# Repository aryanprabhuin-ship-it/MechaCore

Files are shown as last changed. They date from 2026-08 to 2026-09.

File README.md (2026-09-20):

# MechaCore

MechaCore is my custom 60% (61 key) wired mechanical keyboard, its built around a **Raspberry Pi Pico 2** and a completely hand routed 2 layer PCB.

so basicaly i wanted to make a keyboard where i didnt just download somebody elses pcb and put switches in it.. i wanted to actualy understand the matrix, diodes, stabilizers, routing, plate tolerances and how the pcb fits inside a real printable case. i designed the layout, schematic, pcb and the full case from scratch using kicad + fusion 360 and ngl the case part took way more trys then i expected lol

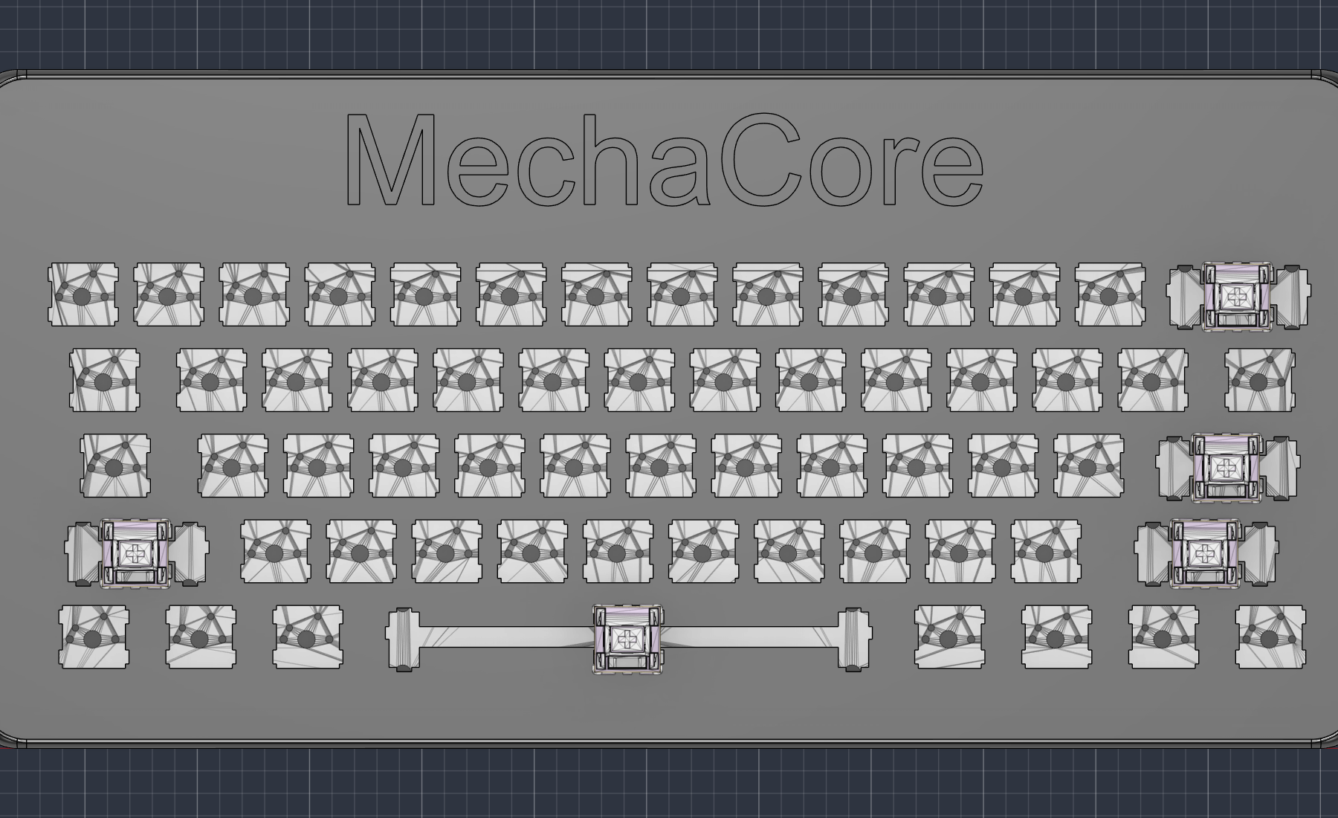
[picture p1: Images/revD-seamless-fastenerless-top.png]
MechaCore Rev D fastenerless enclosure


## why i made this

i use a keyboard for school, coding and pretty much everything, but most custom boards i liked was either super expensive or still used a ready made pcb. making MechaCore was kinda my excuse to learn the full hardware pipeline instead of only assembling parts

main goals i set for myself :

- design a proper **60% ANSI PCB** in kicad with 61 switches
- wire the full matrix directly to a Raspberry Pi Pico 2
- hand route every row, column and diode connection on a real 2 layer board
- support screw-in stabilizers for backspace, enter, both shifts and the 6.25u spacebar
- make a rounded 3d printable bottom case + switch plate in fusion 360
- keep the files actualy manufacturable, not just make a nice looking render
- learn the full pipeline : keyboard layout -> schematic -> pcb -> 3d export -> case -> production files

the routing was easily the most painful bit because the board has 61 switches and basically no room for lazy paths 😭 after alot of moving tracks between front/back copper the pcb reached **0 unconnected items**, which felt kinda unreal after staring at ratsnest lines for so long

## project status

this repo has the full hardware design, cad, manufacturing exports and the Pico 2 firmware. the PCB and case geometry is done, the matrix pinout is locked and the firmware is ready to copy straight onto the controller. the current enclosure is **Rev D**, a two-piece fastenerless design with no screw heads or locator tips visible from the top

whats included :

- kicad project, schematic and fully routed pcb
- full 3d cad (`.f3d`, `.step` and printable `.stl` files)
- current Rev D fused bottom case and blind-snap switch plate exports
- retained Rev B and Rev C CAD archives for design-history / rollback
- production files (bom, positions, designators, ipc netlist and gerber zip)
- 60% ANSI keyboard layout json
- schematic and individual fabrication layer PDFs
- complete Pico 2 firmware with the matching CircuitPython UF2

current hardware summary :

| | |
|---|---|
| Layout | 60% ANSI, 61 keys |
| Controller | Raspberry Pi Pico 2 |
| Connectivity | wired USB through the Pico |
| Matrix | 14 columns x 5 rows, directly connected to the Pico |
| Diodes | 61x Slkor 1N4148W switching diodes, one per key (SOD-123, COL2ROW) |
| Stabilizers | Durock Clear screw-in V2 (6.25u space + 2u / 2.25u / 2.75u) |
| Switches | Akko V3 Penguin Pro |
| Keycaps | Plum Blossom cherry profile shine-through PBT |
| Case | 2 printed parts: fused bottom shell + blind-snap switch plate, no loose case hardware |
| PCB | 2 layer FR4, 300mm x 135.8mm, 1.6mm, green soldermask |
| Firmware | dependency free CircuitPython 10.2.1 USB HID firmware, 2 layers |

the dark rounded case and the big **MechaCore** name on the plate is what kinda gave the whole board its look. the pink plum blossom keycaps should contrast with it nicely, atleast thats the plan once it becomes a real physical board

## images

### current Rev D enclosure

the final top surface is continuous. all six screw stacks from the earlier revisions were removed and both kinematic locator receivers were made blind, so there are no fastener heads or locator dots visible around the key field

Rev D clean top with no visible fasteners

the bottom case still uses six reinforced mounting stations, dual load-spreader spines and the round/expansion datum system. the screw sockets are now undercut receivers for the fused plate collets

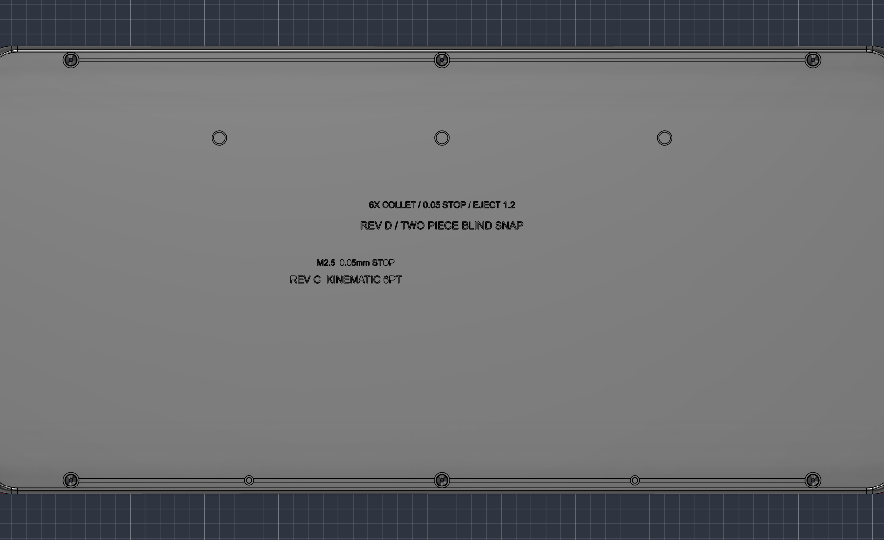
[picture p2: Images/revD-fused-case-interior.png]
Rev D fused bottom-case interior


each plate lock has a split 3.6mm shaft, stepped insertion pilot and 4.3mm retention bead. the relief direction alternates around the plate to reduce sensitivity to print-axis anisotropy

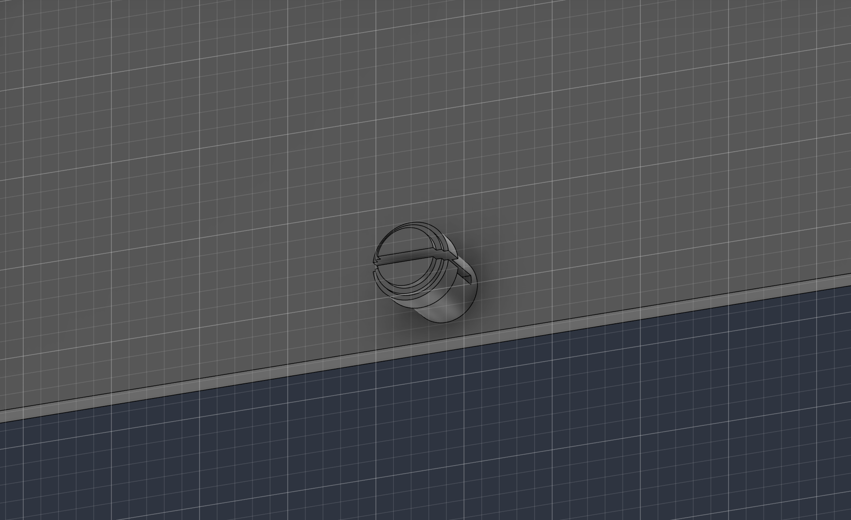
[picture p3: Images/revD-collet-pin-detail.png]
Rev D fused snap-collet detail


the four hollow-cup feet, three PCB deflection catches and six underside ejector ports are fused into the two main printed bodies instead of being separate hardware

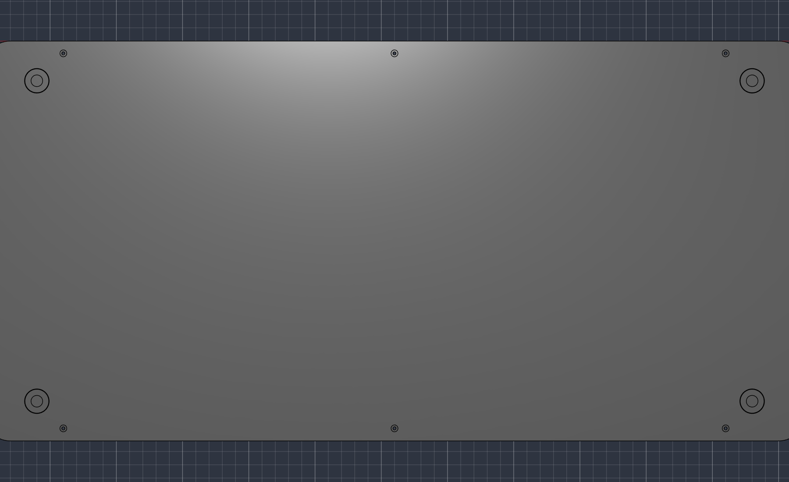
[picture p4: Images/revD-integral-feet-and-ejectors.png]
Rev D integral feet and ejector ports


### PCB and electronics

the complete 14x5 matrix, all 61 switches, 61 diodes, stabilizer symbols and Pico connections are kept in the same KiCad project

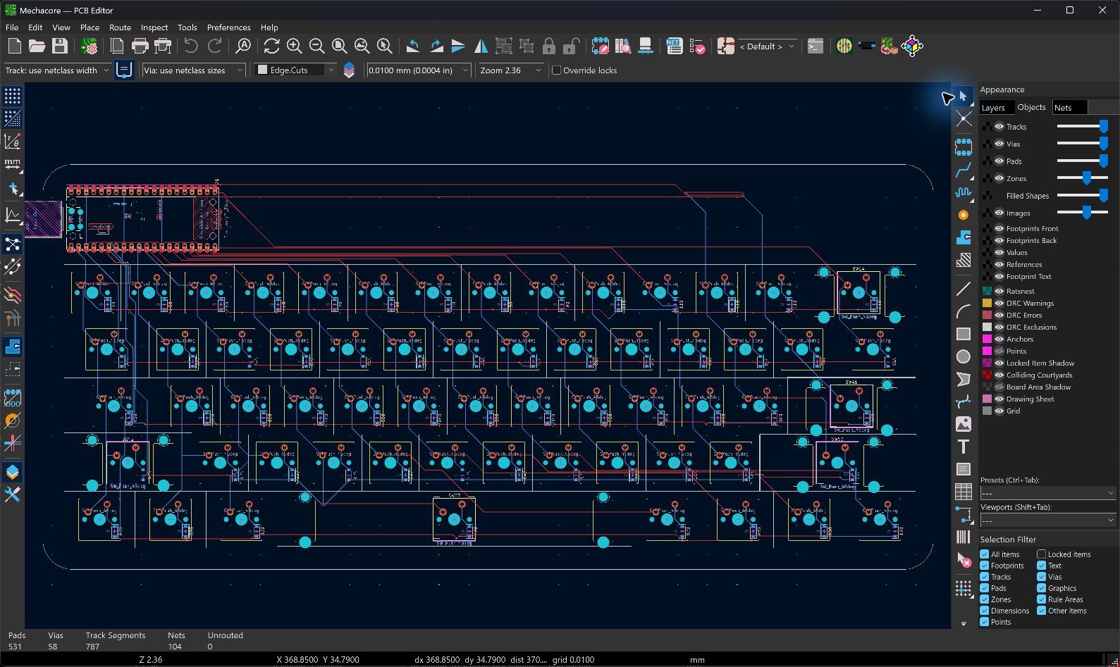
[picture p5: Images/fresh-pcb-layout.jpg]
MechaCore PCB routing in KiCad

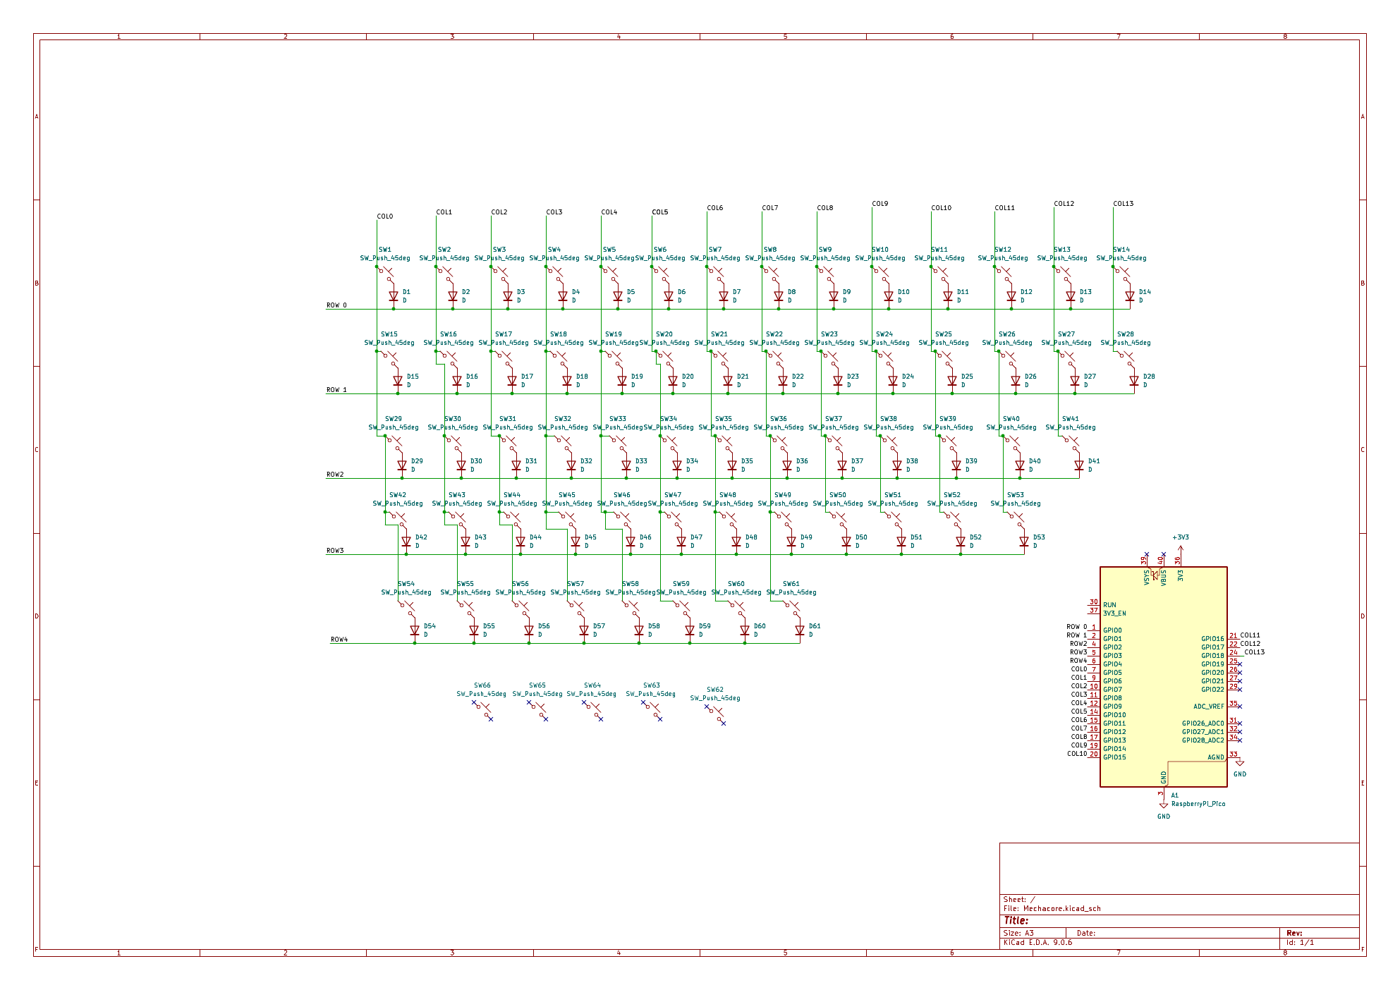
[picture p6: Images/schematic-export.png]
MechaCore schematic

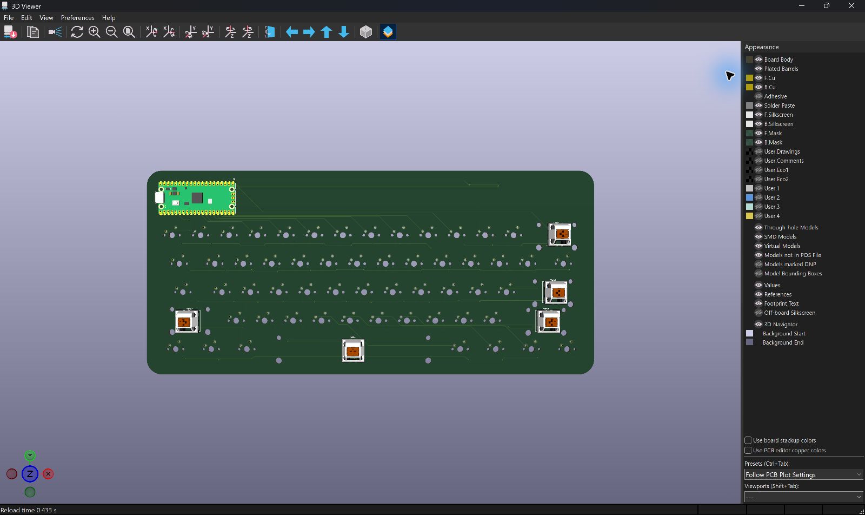
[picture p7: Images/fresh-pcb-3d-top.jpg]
PCB top view in KiCad 3D Viewer

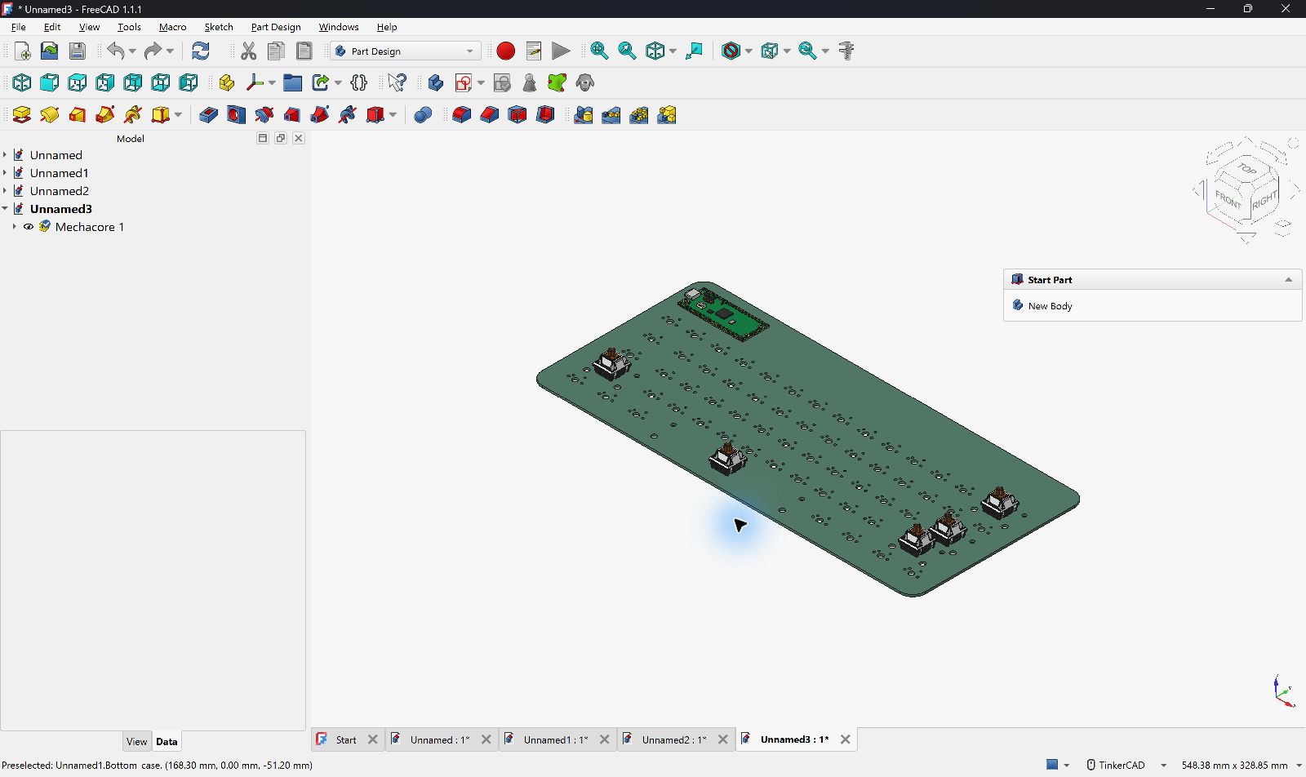
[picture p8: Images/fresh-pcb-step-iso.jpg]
Exported PCB STEP checked in CAD


### earlier enclosure development

these views show the original shell/plate work and are kept as design-history references. the Rev D files below are the current manufacturing set

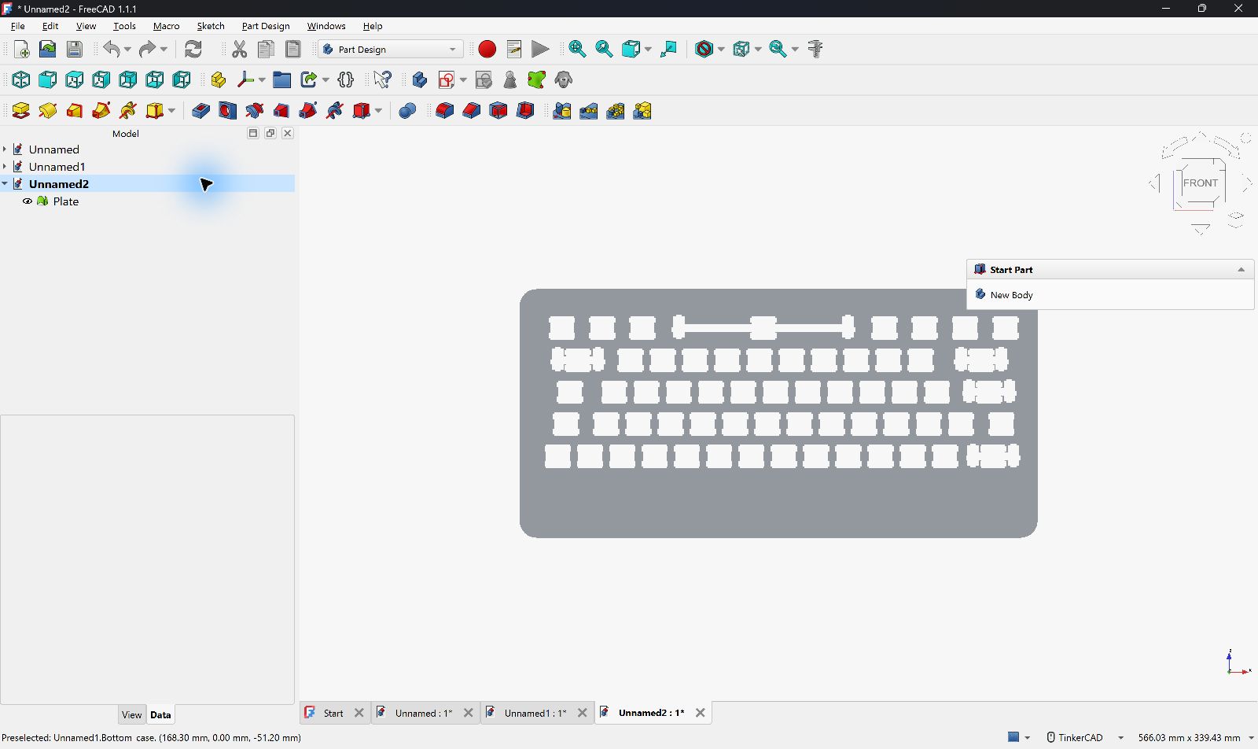
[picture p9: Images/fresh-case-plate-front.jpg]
Original switch and stabilizer plate cutouts

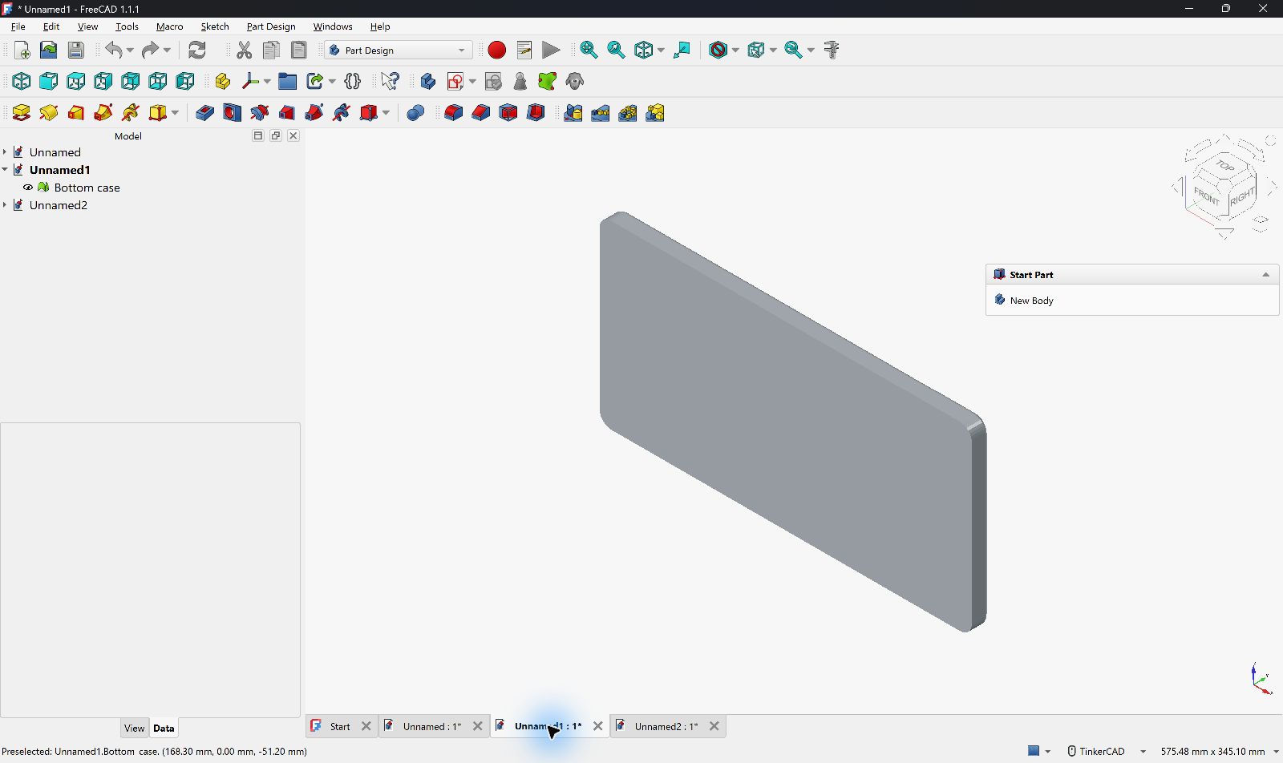
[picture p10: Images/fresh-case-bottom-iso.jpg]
Original bottom case shell


## repository structure

```text
MechaCore/
├── 3D/
│   ├── Case/                 Fusion archives, STEP assemblies and case/plate STLs
│   └── PCB/                  PCB reference model exported as STEP and STL
├── BOM Pics/                 supplier/cart screenshots used during BOM research
├── firmware/                 CircuitPython firmware, boot setup and Pico 2 UF2
├── Images/                   README-ready project, PCB and CAD images
├── layout/                   60% ANSI keyboard-layout JSON
├── PCB/                      KiCad project, schematic, routed PCB and backups
├── PDFs/                     schematic plus individual fabrication-layer PDFs
├── production/               Gerbers, BOM, positions, designators and IPC netlist
├── Working screen shot/      working CAD captures, including Rev B, C and D views
├── bom.csv                   build-cost and purchase-planning BOM
└── README.md
```

`Images/` contains the curated screenshots used by this README. `Working screen shot/` keeps the corresponding working captures so the documentation images can be replaced or compared without opening Fusion or KiCad.

## repo file checklist

important current files in this repo :

- `PCB/Mechacore.kicad_pro`
- `PCB/Mechacore.kicad_sch`
- `PCB/Mechacore.kicad_pcb`
- `3D/Case/Mechacore-overengineered-revD.f3d`  (editable current enclosure)
- `3D/Case/Mechacore-overengineered-revD.step`  (current neutral CAD assembly)
- `3D/Case/Plate-blind-snap-revD.stl`  (print-ready plate with fused collets)
- `3D/Case/Bottom-case-fused-revD.stl`  (print-ready fused case)
- `3D/PCB/Mechacore.step`
- `3D/PCB/Mechacore.stl`
- `layout/keyboard-layout.json`
- `production/bom.csv`
- `production/positions.csv`
- `production/designators.csv`
- `production/netlist.ipc`
- `production/Mechacore.zip`  (gerbers)
- `bom.csv`  (build cost / purchase list)
- `PDFs/Mechacore.pdf`  (schematic print)
- `firmware/code.py`  (MechaCore key scanner + keymap)
- `firmware/boot.py`  (USB name + HID setup)
- `firmware/adafruit-circuitpython-raspberry_pi_pico2-en_US-10.2.1.uf2`

## cad

designed in **Fusion 360**. the current editable enclosure is `3D/Case/Mechacore-overengineered-revD.f3d`, with a STEP assembly beside it and separate production STLs for the case and plate

Rev D is intentionally overengineered while keeping the physical part count low. the Fusion timeline contains **289 items and 52 parameters**, but the finished enclosure is exactly **two printable solids** with no component/hardware occurrences:

- six fused, split snap collets on the plate underside
- six matching undercut sockets inside the reinforced case bosses
- 0.10mm radial retention interference and 0.05mm controlled seating travel
- alternating collet-split directions for print-anisotropy compensation
- round + expansion kinematic locators hidden below a 0.6mm plate roof
- six 1.2mm underside ejector ports for non-destructive service removal
- fused hollow-cup feet and fused PCB anti-sag catches
- existing wall gussets and dual load-spreader spines retained for the clamp/load path

to assemble it, align the blind locator pair and press evenly above the six edge stations until the retention beads seat in their undercut cavities. for removal, release the stations progressively through the underside ejector ports instead of bending one side of the plate

older CAD is intentionally kept in the same folder:

| Revision | Purpose |
|---|---|
| Original / unsuffixed | initial shell and plate baseline |
| Rev B | first proper six-point M2.5 screw mounting system |
| Rev C | screws, inserts, isolation washers, compression stops, feet and PCB supports |
| **Rev D** | current two-piece blind-snap design with fused service features |

the exact pcb was also exported as both STEP and STL in `3D/PCB/`. i used that model inside the case design instead of guessing the board outline, especially for the rounded corners, Pico usb opening, solder clearance and stabilizer holes

## firmware

firmware is finaly in the repo under `firmware/`. its a small dependency free CircuitPython setup written just for MechaCore, so theres no KMK folder, package install or placeholder pin list to fix later. the GPIO map was copied directly from the finished kicad PCB and the bundled UF2 is the official stable [CircuitPython Pico 2 build](https://circuitpython.org/board/raspberry_pi_pico2/)

| | |
|---|---|
| Runtime | CircuitPython 10.2.1 for Raspberry Pi Pico 2 |
| Rows | GP0, GP1, GP2, GP3, GP4 |
| Columns | GP5 through GP18 |
| Matrix | 5 rows x 14 columns, 61 populated positions |
| Diodes | column anode to row cathode (`columns_to_anodes=True`) |
| Debounce | 3 stable scans at 2ms, around 6ms total |
| USB | standard keyboard + consumer control HID |
| Rollover | 6 normal keys plus all modifiers |

the base layer follows the actual keycap layout :

```text
`     1   2   3   4   5   6   7   8   9   0   -   =   Backspace
Tab   Q   W   E   R   T   Y   U   I   O   P   [   ]   \
Caps  A   S   D   F   G   H   J   K   L   ;   '       Enter
Shift Z   X   C   V   B   N   M   ,   .   /           Shift
Ctrl  Win Alt             Space             Alt Win Menu/Fn Ctrl
```

the Menu key still works like a normal Menu key when tapped. hold it for 180ms or press it together with another key and it becomes Fn

- `Fn + backtick` = Escape
- `Fn + 1` through `Fn + =` = F1 through F12
- `Fn + Backspace` = Delete
- `Fn + U / I / O / P` = Home / Up / End / Page Up
- `Fn + J / K / L / ;` = Left / Down / Right / Page Down
- `Fn + Q / W / E` = Previous track / Play-Pause / Next track
- `Fn + M`, `Fn + ,`, `Fn + .`, `Fn + /` = Mute / Volume Down / Volume Up / Play-Pause

### flashing it

1. hold the BOOTSEL button on the Pico 2 while plugging the keyboard into usb
2. open the new `RP2350` drive and copy `firmware/adafruit-circuitpython-raspberry_pi_pico2-en_US-10.2.1.uf2` onto it
3. after it restarts as `CIRCUITPY`, copy `firmware/boot.py` and `firmware/code.py` to the root of that drive
4. unplug and reconnect once so the USB setup from `boot.py` loads cleanly

thats it, no pin edits or extra libraries are needed. the keyboard shows up as **MechaCore** and the files stay editable from the `CIRCUITPY` drive if i ever wanna change the layout later

## bom (summary)

full purchase list is in `bom.csv`. these prices are the rough planned cost in indian rupees, nothing was ordered yet

| # | Name | Purpose | Qty | Cost (₹) | Distributor | Link |
|---|---|---|-----|---|---|---|
| 1 | PCB fabrication | 2 layer MechaCore boards | 5 boards | 5288 | Robu | [Buy](https://robu.in/product/online-pcb-manufacturing-service/) |
| 2 | 3D printed case | bottom shell + plate | 1 set | own funded| Hack Club | — |
| 3 | Plum Blossom Cherry Profile Shine-Through PBT Keycap Set | keycaps to actualy type on | 1 set | own funded | Curiosity Caps | [Buy](https://curiositycaps.in/products/plum-blossom-cherry-profile-shine-through-dye-sublimation-pbt-keycap-set) |
| 4 | Durock Clear Screw-In Stabilizers V2 | keeps the large keys stable | 1 set | 1595 | StacksKB | [Buy](https://stackskb.com/store/durock-clear-screw-in-stabilizers-v2/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) |
| 5 | Akko V3 Penguin Pro Switch (Pack of 45) | mechanical switches + spares | 1 pack | 1,199 | StacksKB | [Buy](https://stackskb.com/store/akko-v3-cream-black-pro-switch-pack-of-45/) |
| 6 | Raspberry Pi Pico 2 | microcontroller / the brains | 1 | 519 | Robu | [Buy](https://robu.in/product/raspberry-pi-pico-2/) |
| 7 | Slkor 1N4148W SOD-123 switching diodes | one diode per switch + some spares | 70 pcs | 100.10 | Robu | [Buy](https://robu.in/product/1n4148w-slkor-75v-1v-4ns-150ma-sod-123-switching-diodes-rohs/) |

**rough total bom cost : ₹8,701.10**

---

thanks for reading,, if you build one or spot something weird feel free to open a issue. this was my first full keyboard pcb + case made from scratch so its deffinately not perfect but i learnt a insane amount making it :)

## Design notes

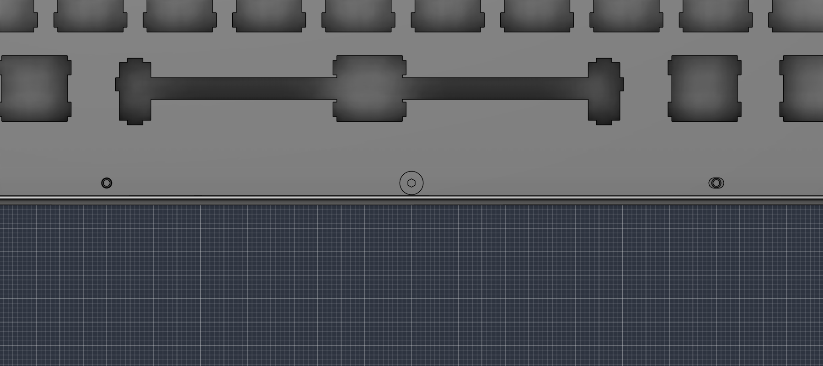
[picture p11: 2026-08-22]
Images/revC-kinematic-locators-detail.png

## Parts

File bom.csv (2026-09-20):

Part | Link | Provider | Price(Rupees)
PCB | https://robu.in/product/online-pcb-manufacturing-service/ | Robu | 5288
3d printing | hackclub | hackclub | own funded
Plum Blossom Cherry | https://curiositycaps.in/products/plum-blossom-cherry-profile-shine-through-dye-sublimation-pbt-keycap-set | Curiosity caps | own funded
Durock Clear Screw-In Stabilizers V2 | https://stackskb.com/store/durock-clear-screw-in-stabilizers-v2/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 | StacksKB | 1595
Akko V3 Penguin Pro Switch (Pack of 45) | https://stackskb.com/store/akko-v3-cream-black-pro-switch-pack-of-45/ | StacksKB | 1,199
Pico 2 | https://robu.in/product/raspberry-pi-pico-2/ | Robu | 519
Slkor 1N4148W SOD-123 switching diodes (70 pcs) | https://robu.in/product/1n4148w-slkor-75v-1v-4ns-150ma-sod-123-switching-diodes-rohs/ | Robu | 100.1
 |  |  | 8701.1

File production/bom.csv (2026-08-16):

Designator | Footprint | Quantity | Value | LCSC Part #
A1 | RaspberryPi_Pico_Common_Unspecified | 1 | RaspberryPi_Pico
D1, D10, D11, D12, D13, D14, D15, D16, D17, D18, D19, D2, D20, D21, D22, D23, D24, D25, D26, D27, D28, D29, D3, D30, D31, D32, D33, D34, D35, D36, D37, D38, D39, D4, D40, D41, D42, D43, D44, D45, D46, D47, D48, D49, D5, D50, D51, D52, D53, D54, D55, D56, D57, D58, D59, D6, D60, D61, D7, D8, D9 | D_SOD-123 | 61 | 1N4148W
SW1, SW10, SW11, SW12, SW13, SW16, SW17, SW18, SW19, SW2, SW20, SW21, SW22, SW23, SW24, SW25, SW26, SW27, SW3, SW30, SW31, SW32, SW33, SW34, SW35, SW36, SW37, SW38, SW39, SW4, SW40, SW43, SW44, SW45, SW46, SW47, SW48, SW49, SW5, SW50, SW51, SW52, SW6, SW7, SW8, SW9 | SW_MX_1u | 46 | SW_Push_45deg
SW14 | SW_Cherry_MX_PCB_2.00u | 1 | SW_Push_45deg
SW15, SW28 | SW_MX_1.5u | 2 | SW_Push_45deg
SW29 | SW_MX_1.75u | 1 | SW_Push_45deg
SW41, SW42 | SW_Cherry_MX_PCB_2.25u | 2 | SW_Push_45deg
SW53 | SW_Cherry_MX_PCB_2.75u | 1 | SW_Push_45deg
SW54, SW55, SW56, SW58, SW59, SW60, SW61 | SW_MX_1.25u | 7 | SW_Push_45deg
SW57 | SW_Cherry_MX_PCB_6.25u | 1 | SW_Push_45deg
SW62 | STAB_MX_2u | 1 | SW_Push_45deg
SW63, SW64 | STAB_MX_2.25u | 2 | SW_Push_45deg
SW65 | STAB_MX_2.75u | 1 | SW_Push_45deg
SW66 | STAB_MX_6.25u | 1 | SW_Push_45deg

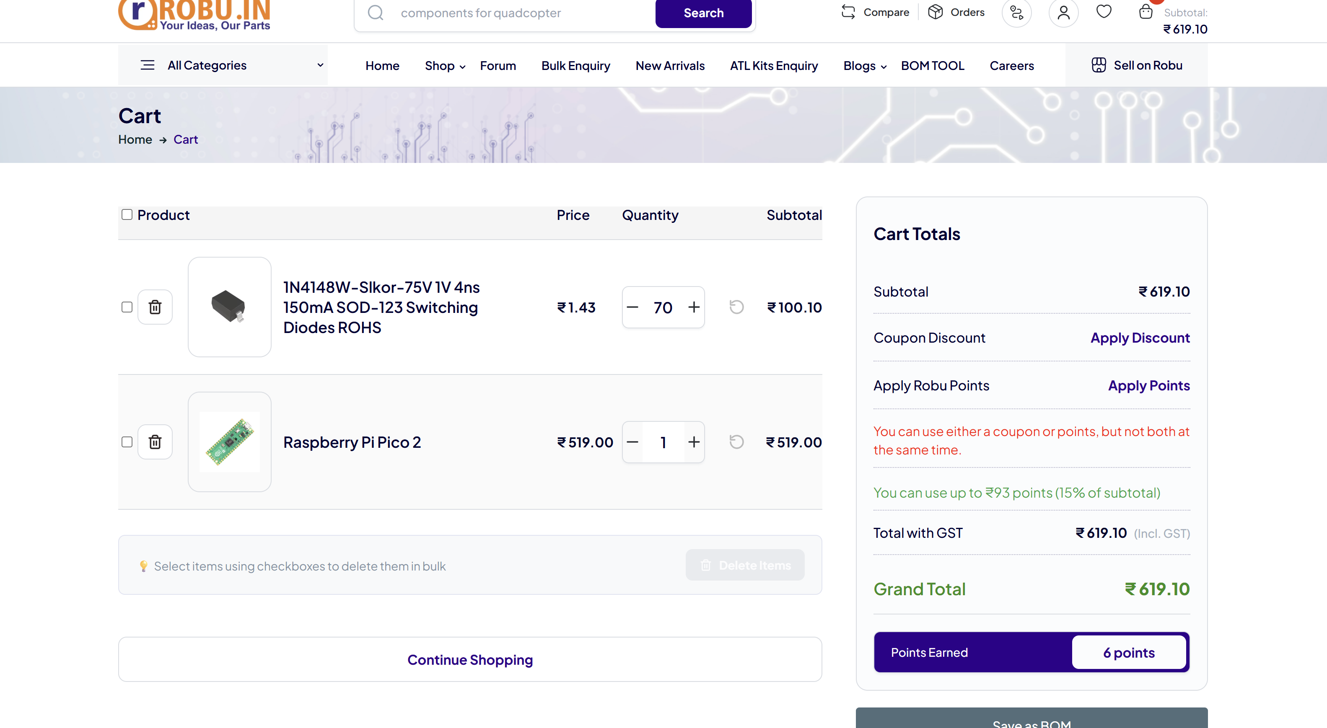
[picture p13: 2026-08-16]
BOM Pics/Screenshot 2026-08-16 123939.png

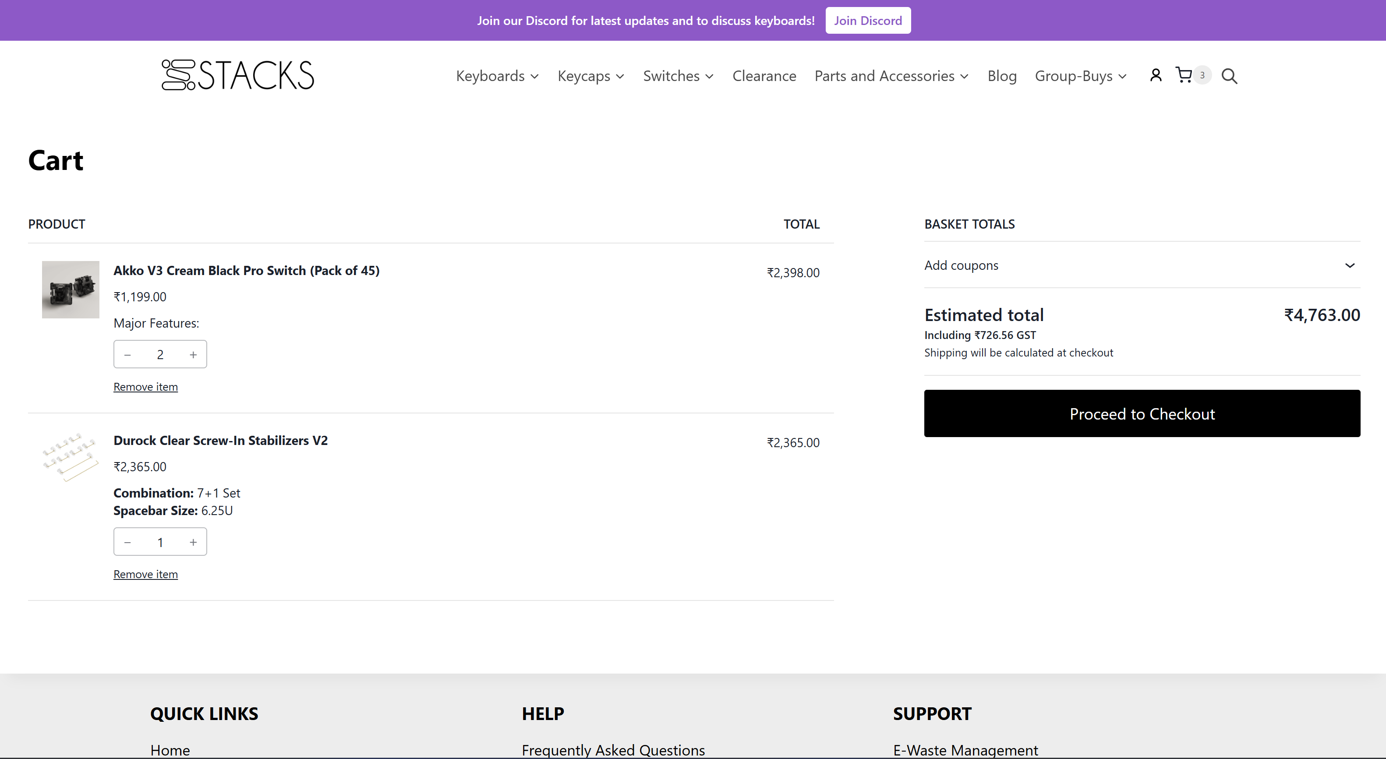
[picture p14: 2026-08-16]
BOM Pics/Screenshot 2026-08-16 123547.png

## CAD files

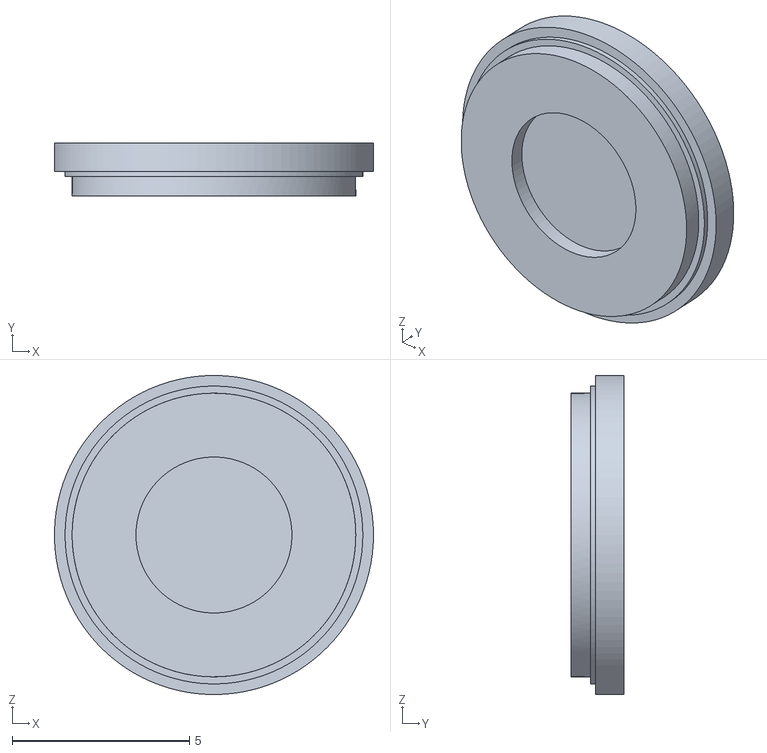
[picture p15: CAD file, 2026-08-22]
3D/Case/TPU-foot-8mm-revC.stl
9.00 x 1.50 x 9.00

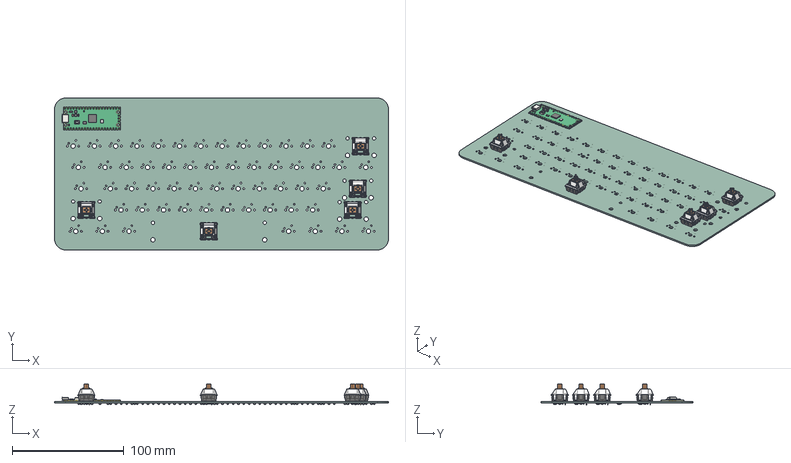
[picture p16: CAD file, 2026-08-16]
3D/PCB/Mechacore.step
298.8 x 136.0 x 18.6 mm
RaspberryPi_Pico_Module_KiCad
SW_Cherry_MX_PCB x 5
D_SOD-123 x 61
Mechacore_PCB

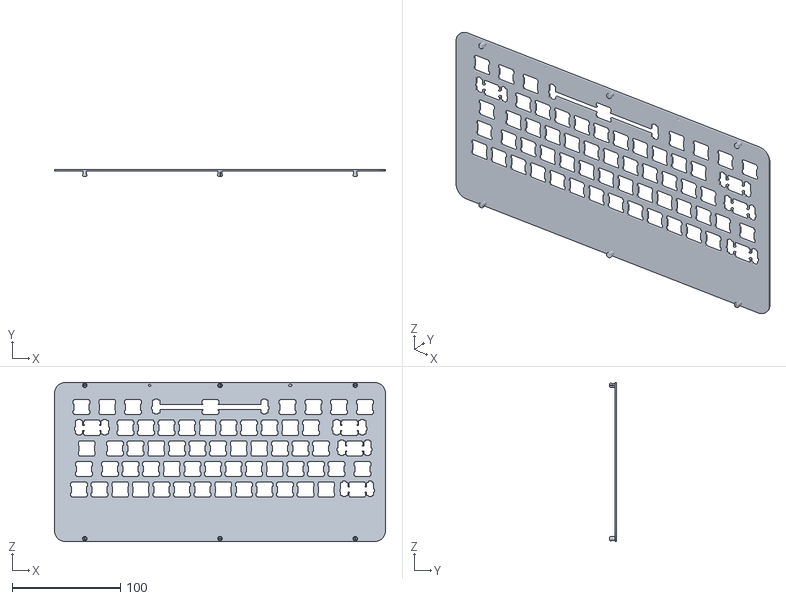
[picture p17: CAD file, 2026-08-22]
3D/Case/Plate-blind-snap-revD.stl
305.9 x 6.80 x 147.0

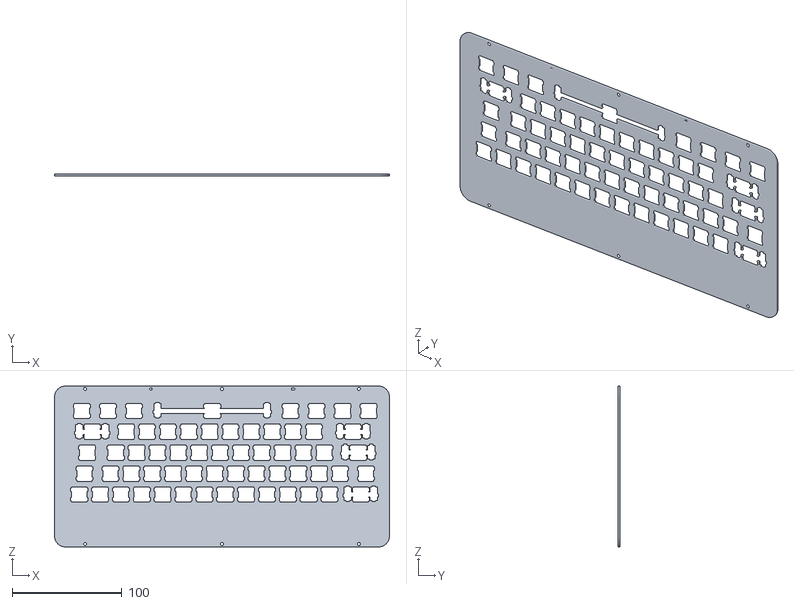
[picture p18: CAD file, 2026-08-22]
3D/Case/Plate-overengineered-revC.stl
305.9 x 1.60 x 147.0

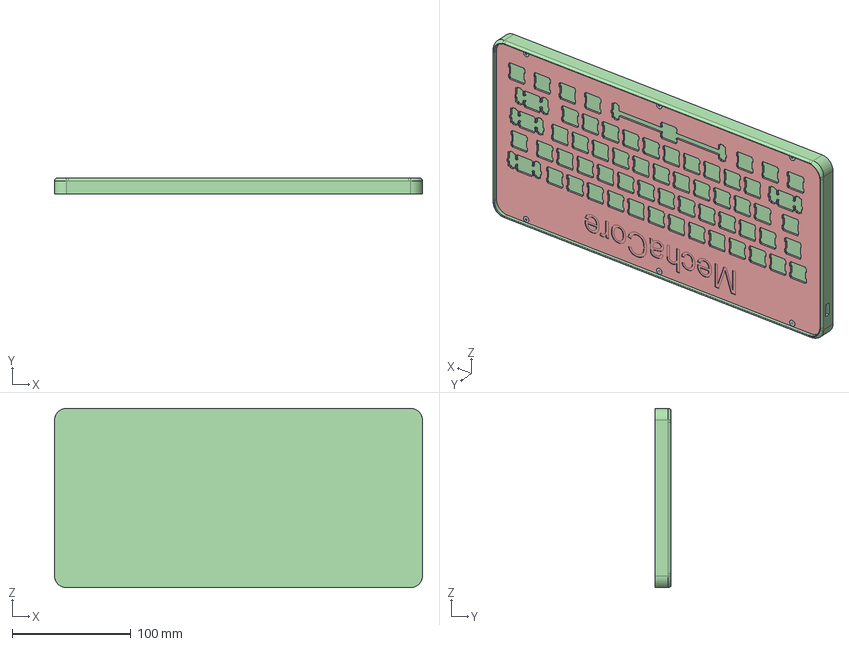
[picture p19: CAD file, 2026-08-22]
3D/Case/Mechacore-mounting-revB.step
310.0 x 13.9 x 151.0 mm

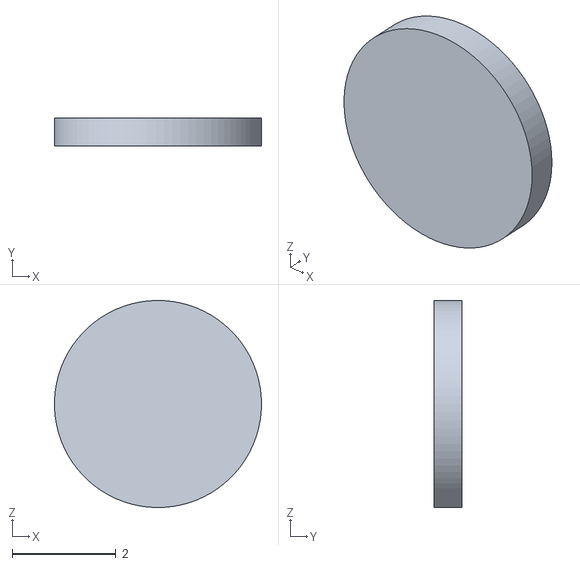
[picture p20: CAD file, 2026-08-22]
3D/Case/PCB-support-pad-revC.stl
4.00 x 0.539 x 4.00

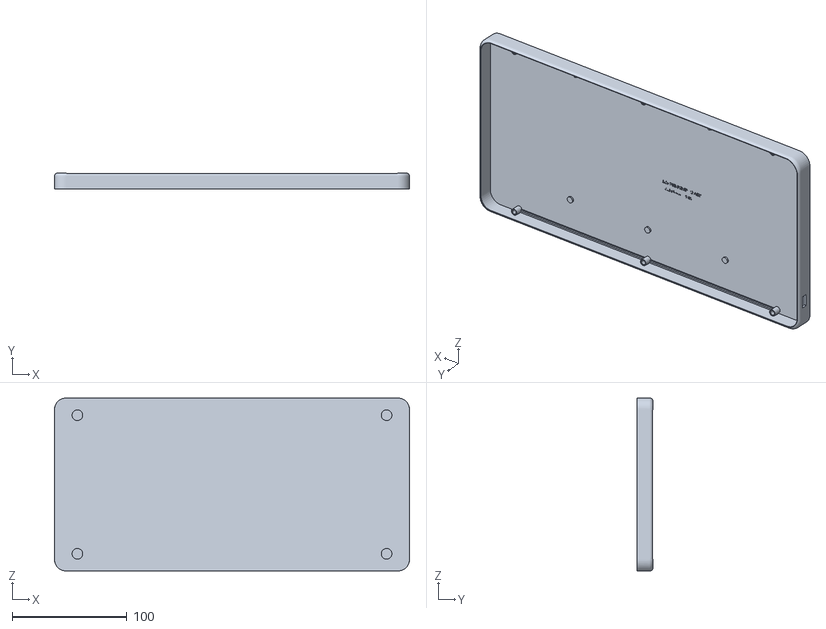
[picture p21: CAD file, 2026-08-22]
3D/Case/Bottom-case-overengineered-revC.stl
310.0 x 13.9 x 151.0

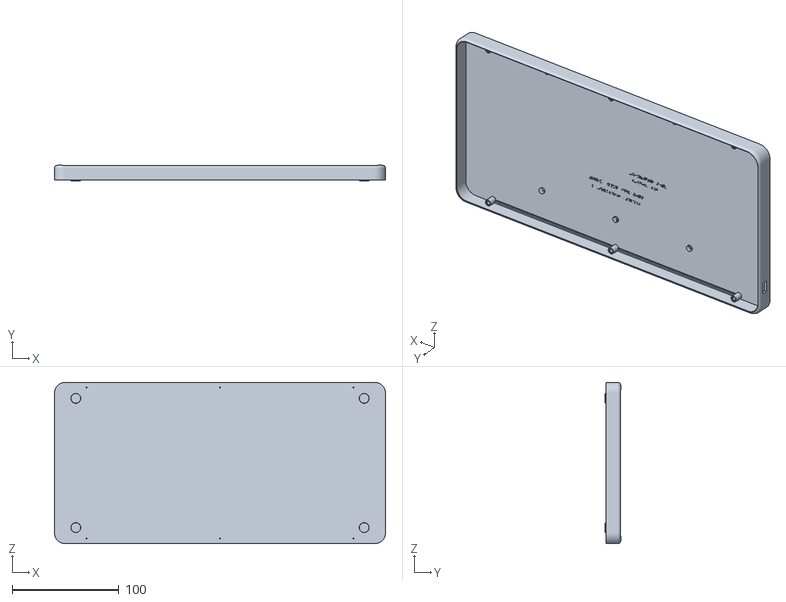
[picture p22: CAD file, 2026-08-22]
3D/Case/Bottom-case-fused-revD.stl
310.0 x 14.6 x 151.0

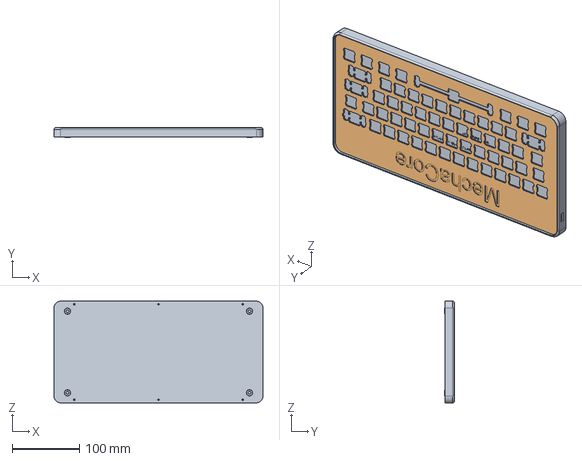
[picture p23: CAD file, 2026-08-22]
3D/Case/Mechacore-overengineered-revD.step
310.0 x 14.6 x 151.0 mm

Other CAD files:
3D/Case/Plate-mounting-revB.stl
3D/Case/Bottom-case-mounting-revB.stl
3D/Case/Plate.stl
3D/Case/Mechacore.step
3D/Case/Bottom case.stl
3D/Case/Mechacore-overengineered-revC.step
3D/Case/Mechacore-mounting-revB.f3d
3D/Case/Mechacore-overengineered-revC.f3d
3D/Case/Mechacore-overengineered-revD.f3d
3D/Case/Mechacore.f3d

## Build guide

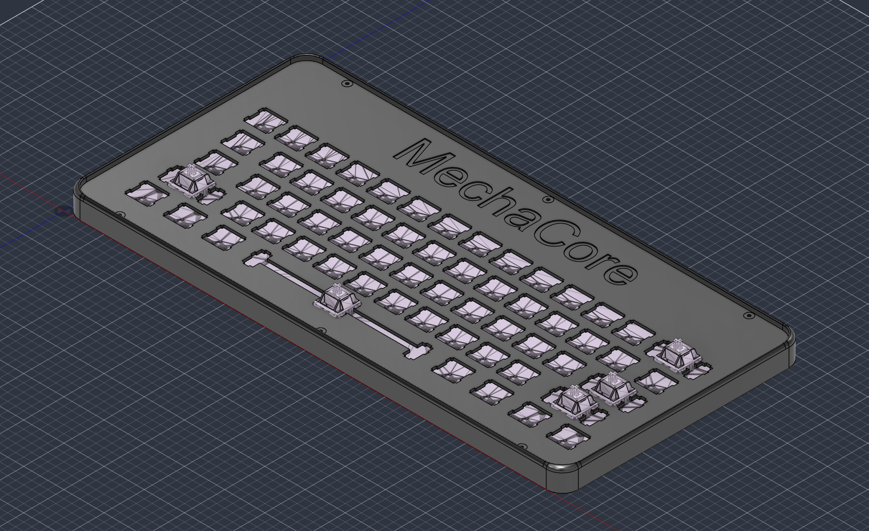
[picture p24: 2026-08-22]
Images/mounting-system-assembled-top.png

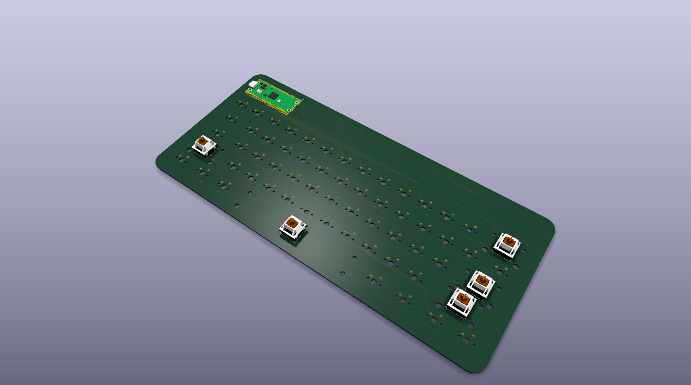
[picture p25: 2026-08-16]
Images/pcb-step-check.png

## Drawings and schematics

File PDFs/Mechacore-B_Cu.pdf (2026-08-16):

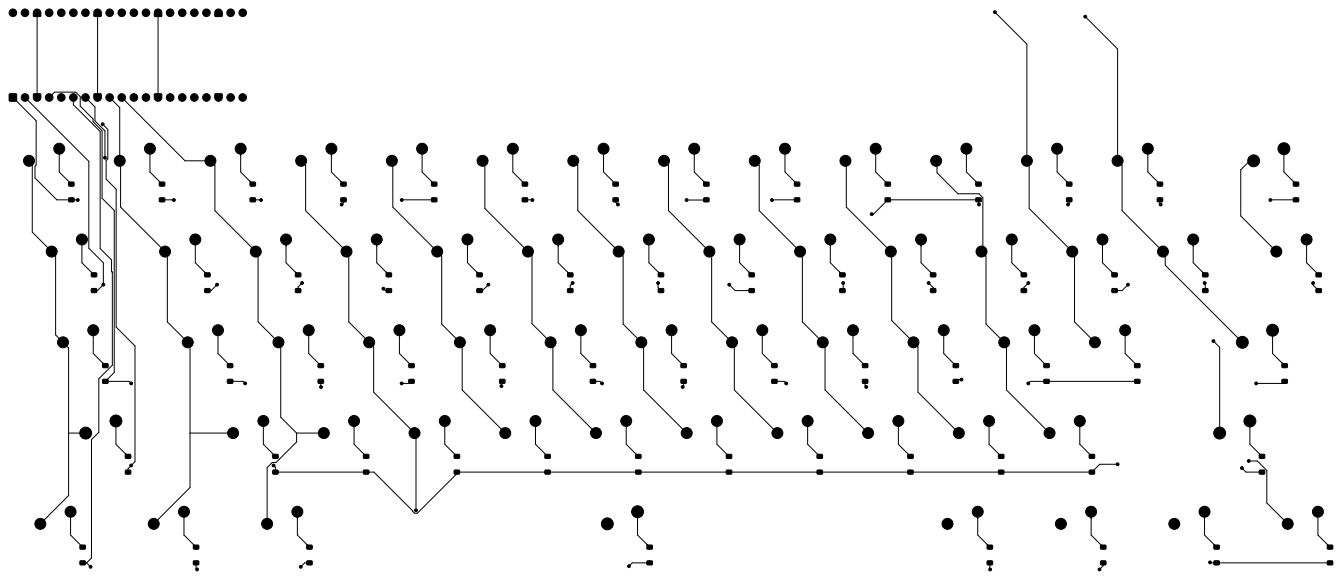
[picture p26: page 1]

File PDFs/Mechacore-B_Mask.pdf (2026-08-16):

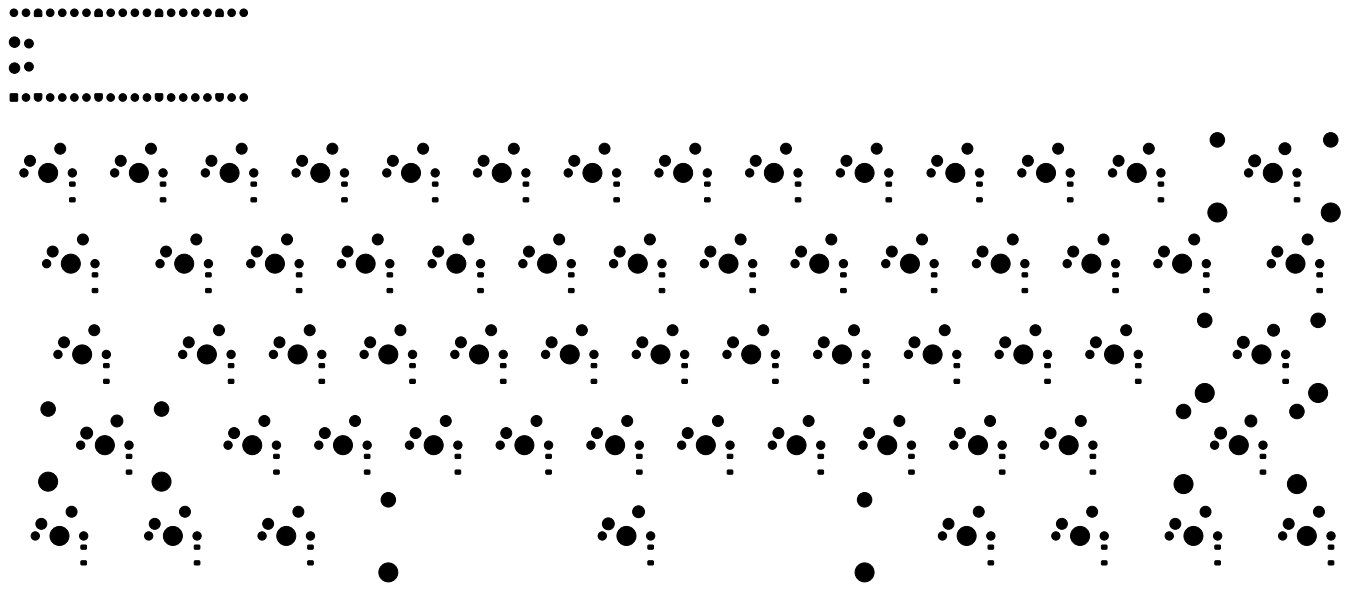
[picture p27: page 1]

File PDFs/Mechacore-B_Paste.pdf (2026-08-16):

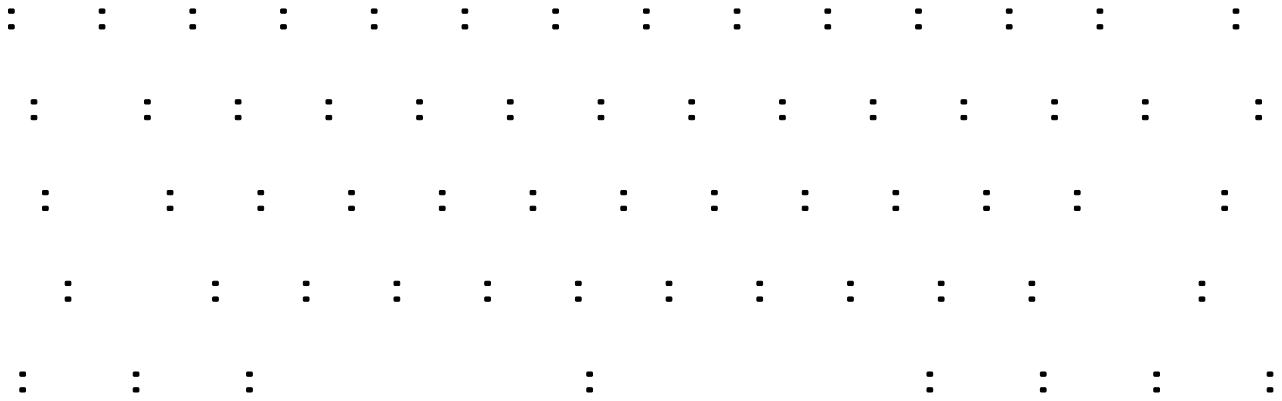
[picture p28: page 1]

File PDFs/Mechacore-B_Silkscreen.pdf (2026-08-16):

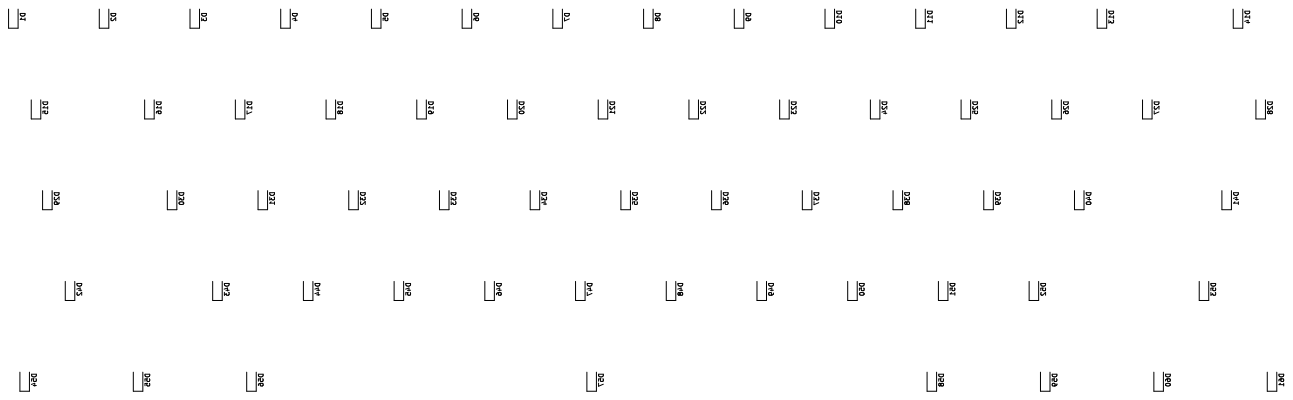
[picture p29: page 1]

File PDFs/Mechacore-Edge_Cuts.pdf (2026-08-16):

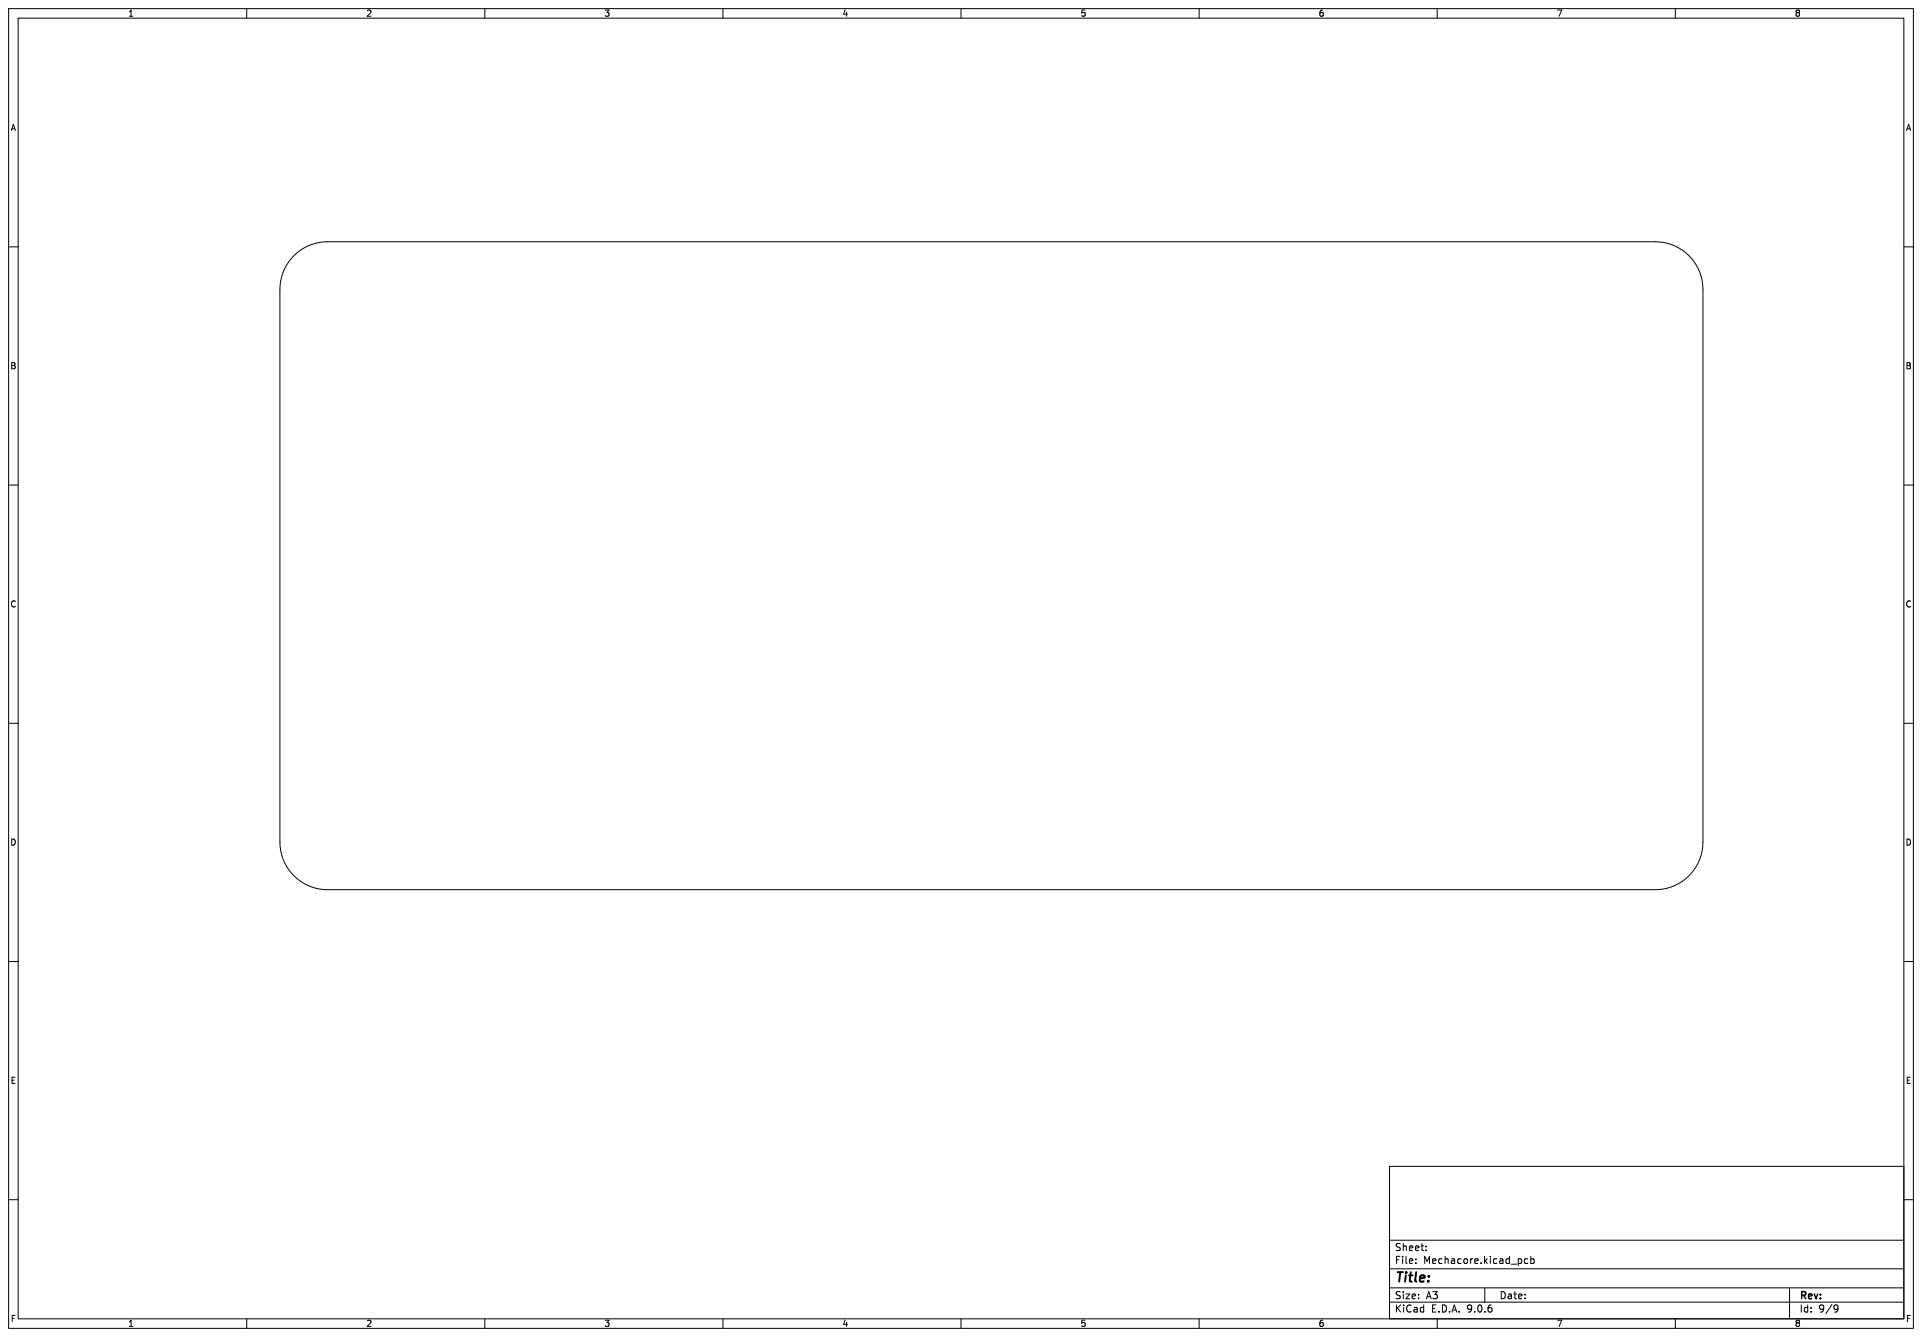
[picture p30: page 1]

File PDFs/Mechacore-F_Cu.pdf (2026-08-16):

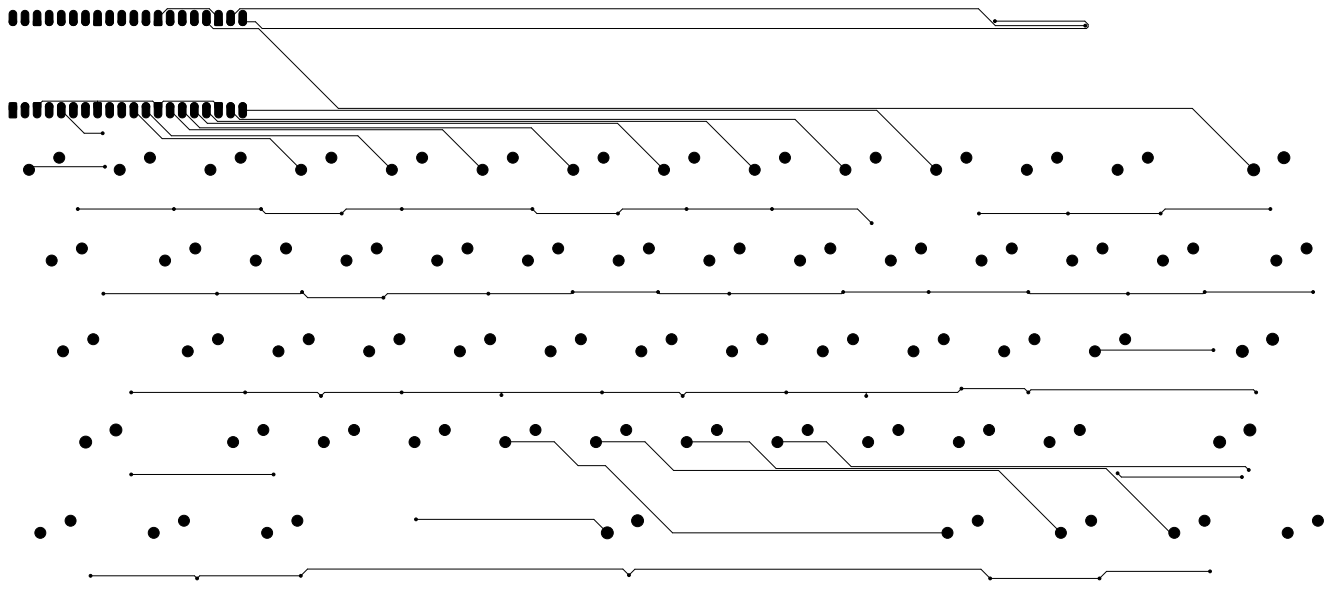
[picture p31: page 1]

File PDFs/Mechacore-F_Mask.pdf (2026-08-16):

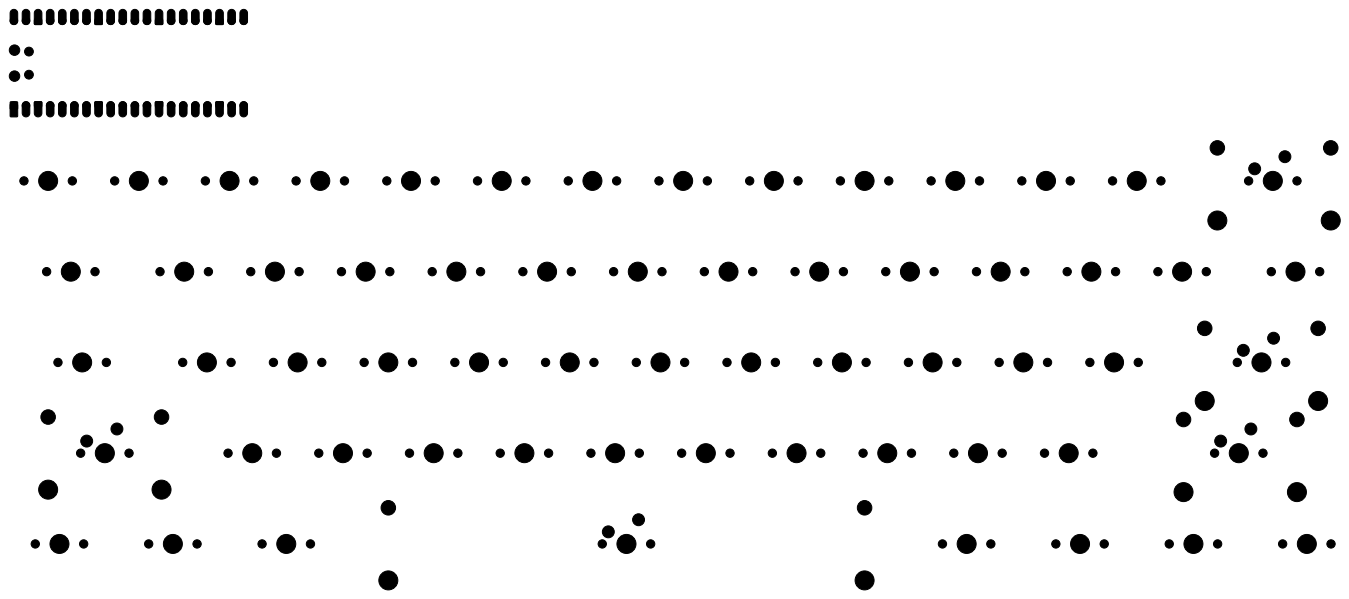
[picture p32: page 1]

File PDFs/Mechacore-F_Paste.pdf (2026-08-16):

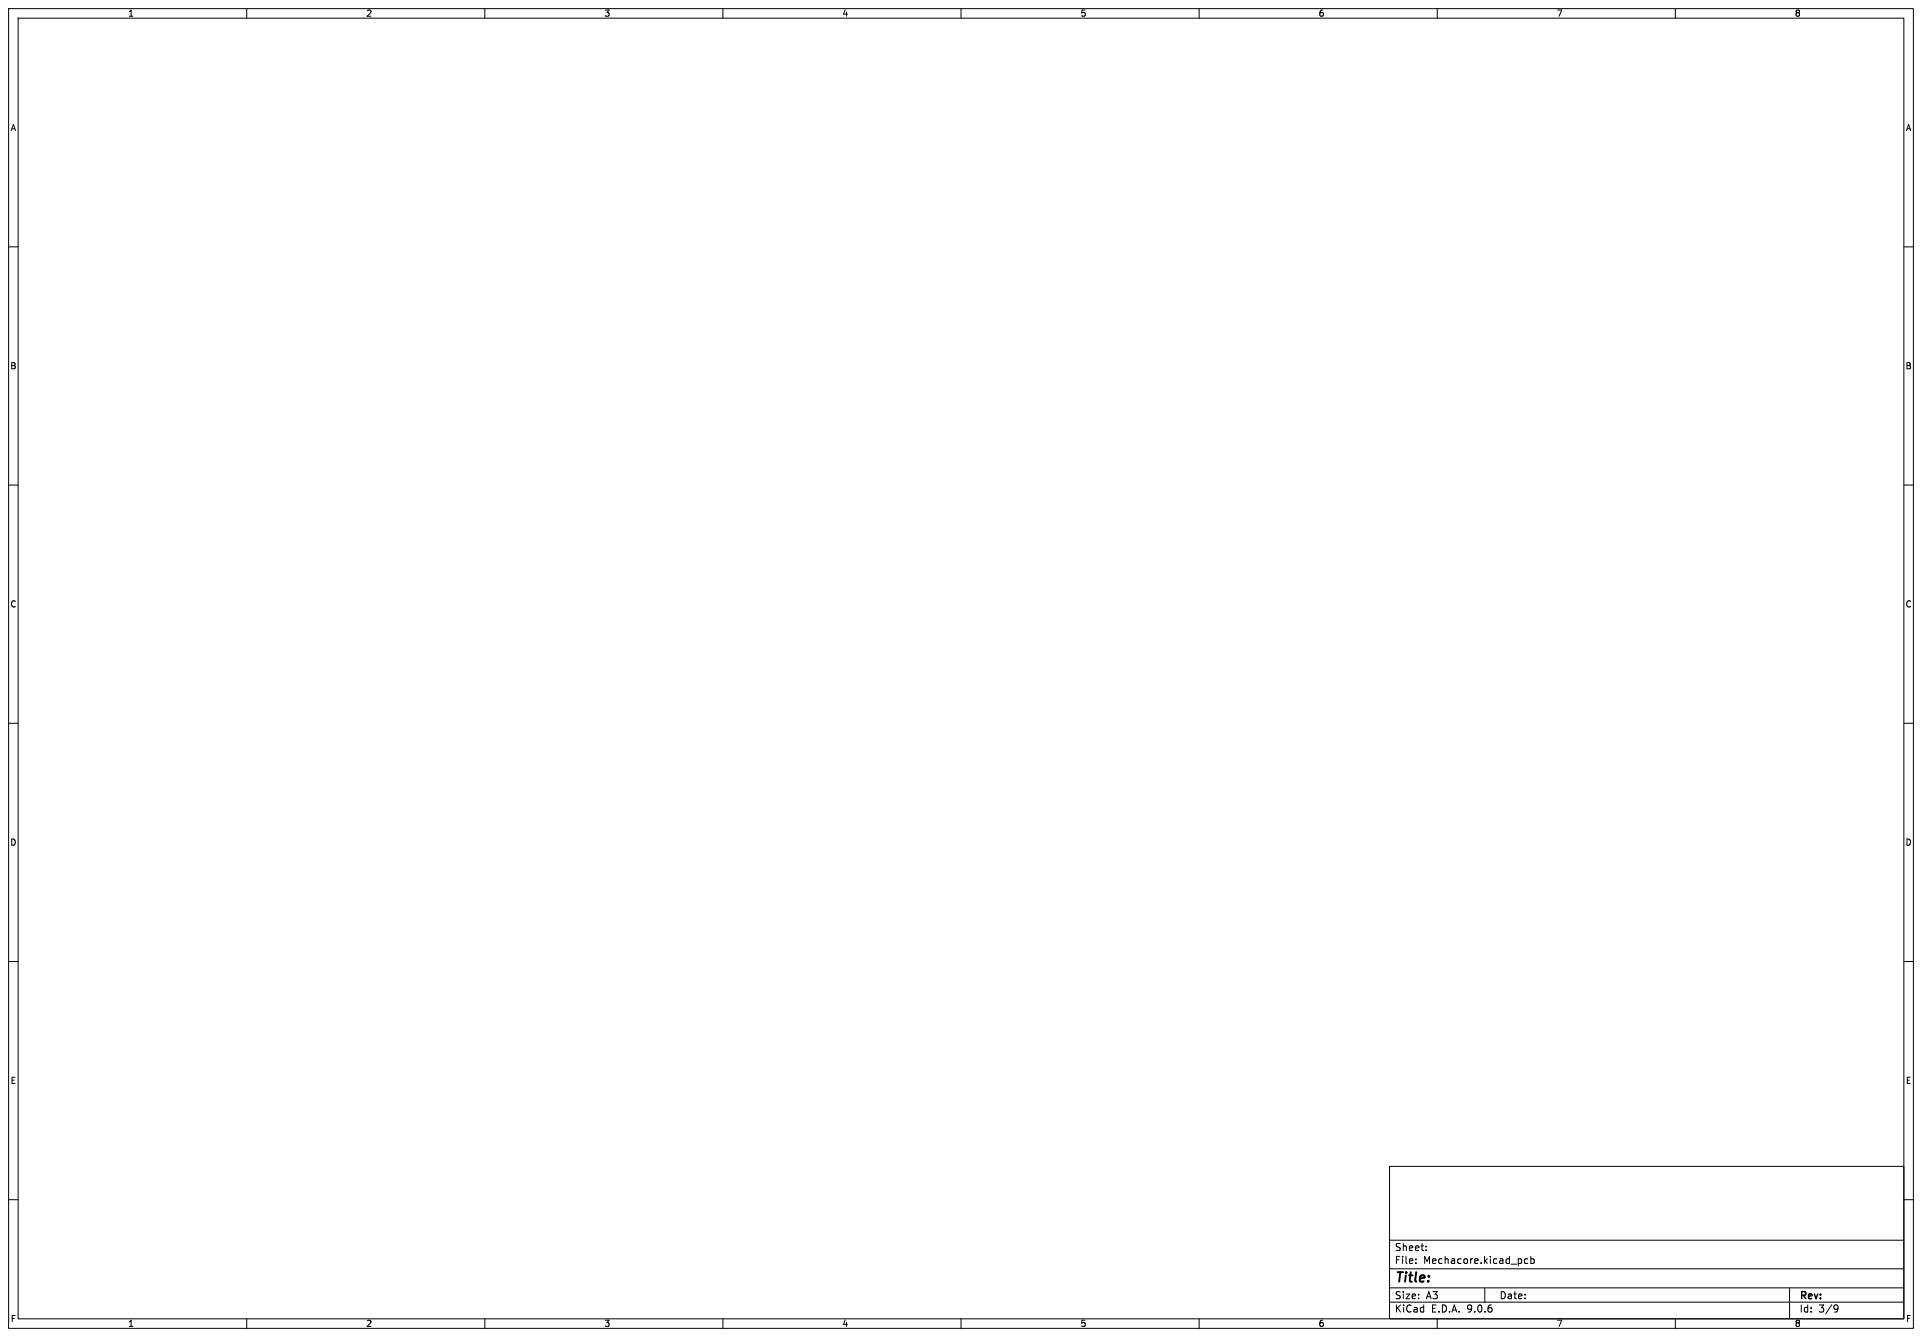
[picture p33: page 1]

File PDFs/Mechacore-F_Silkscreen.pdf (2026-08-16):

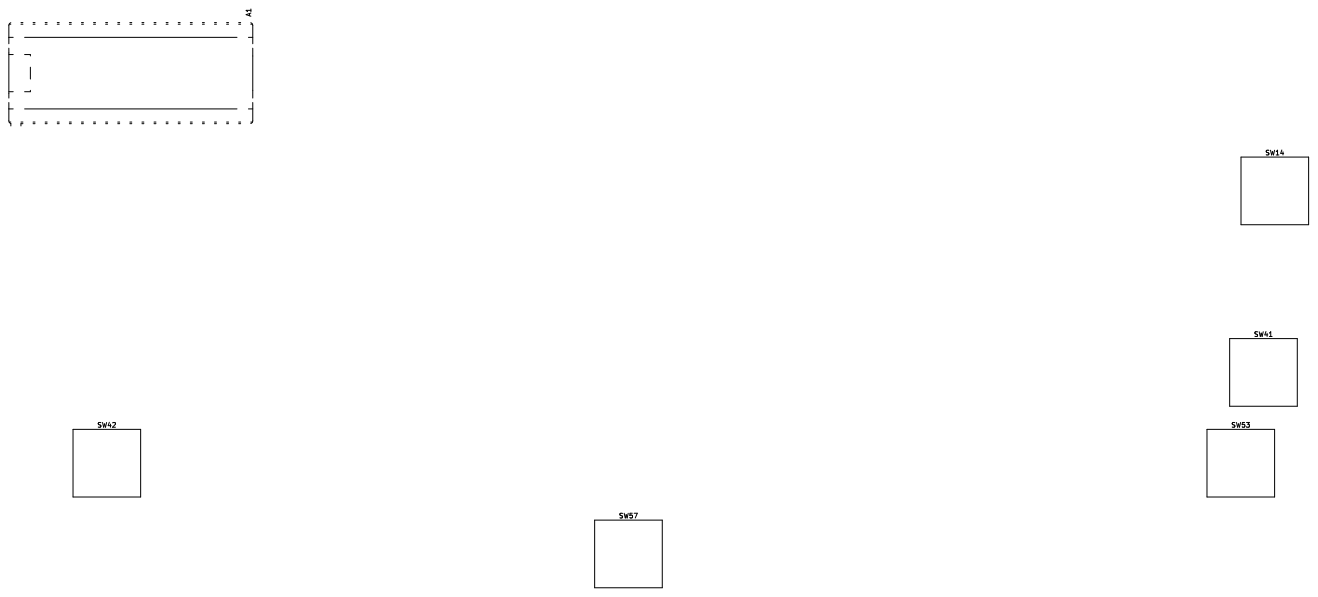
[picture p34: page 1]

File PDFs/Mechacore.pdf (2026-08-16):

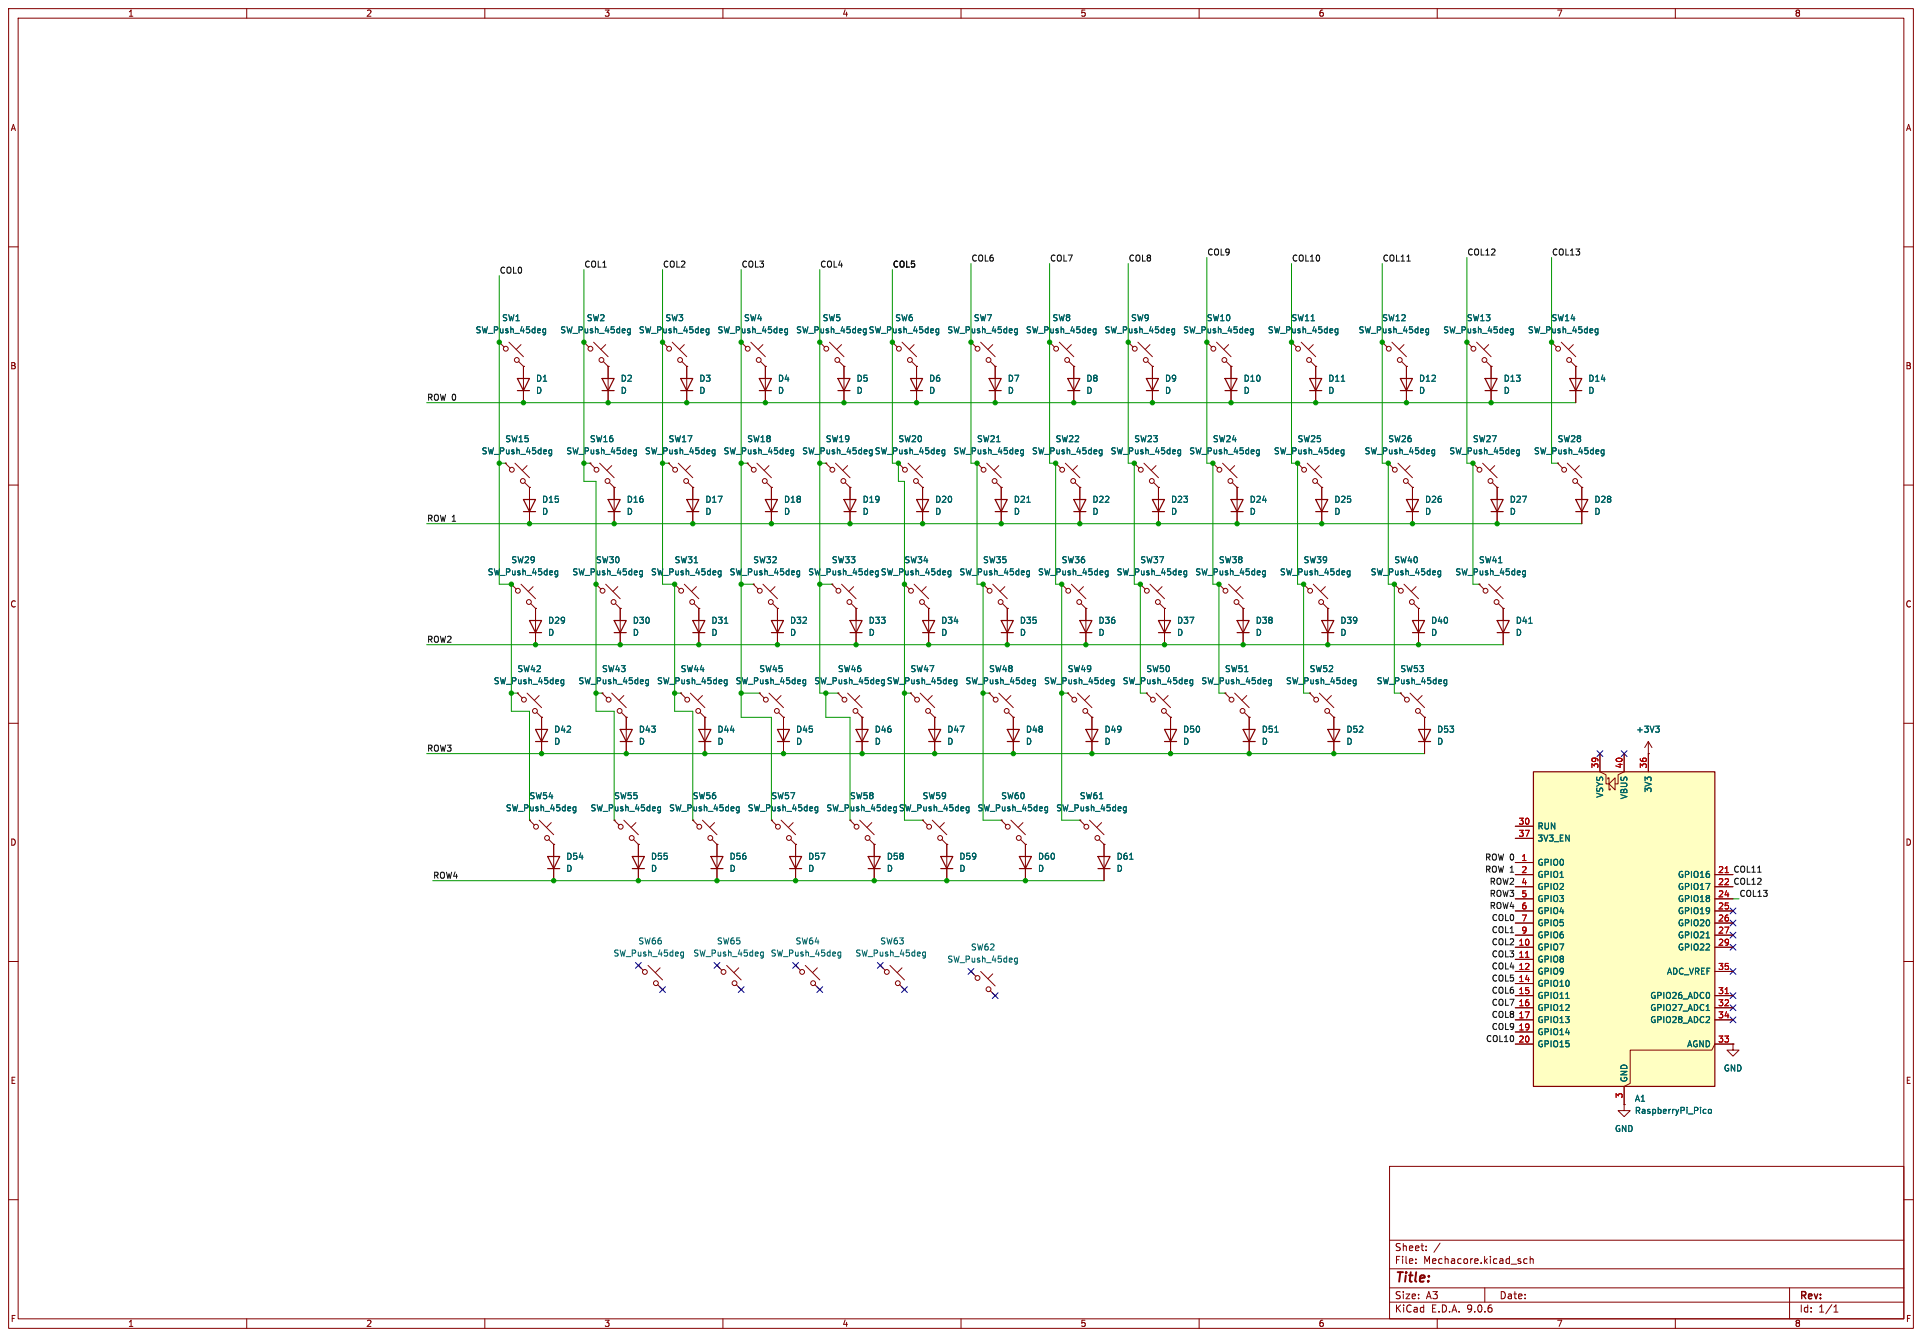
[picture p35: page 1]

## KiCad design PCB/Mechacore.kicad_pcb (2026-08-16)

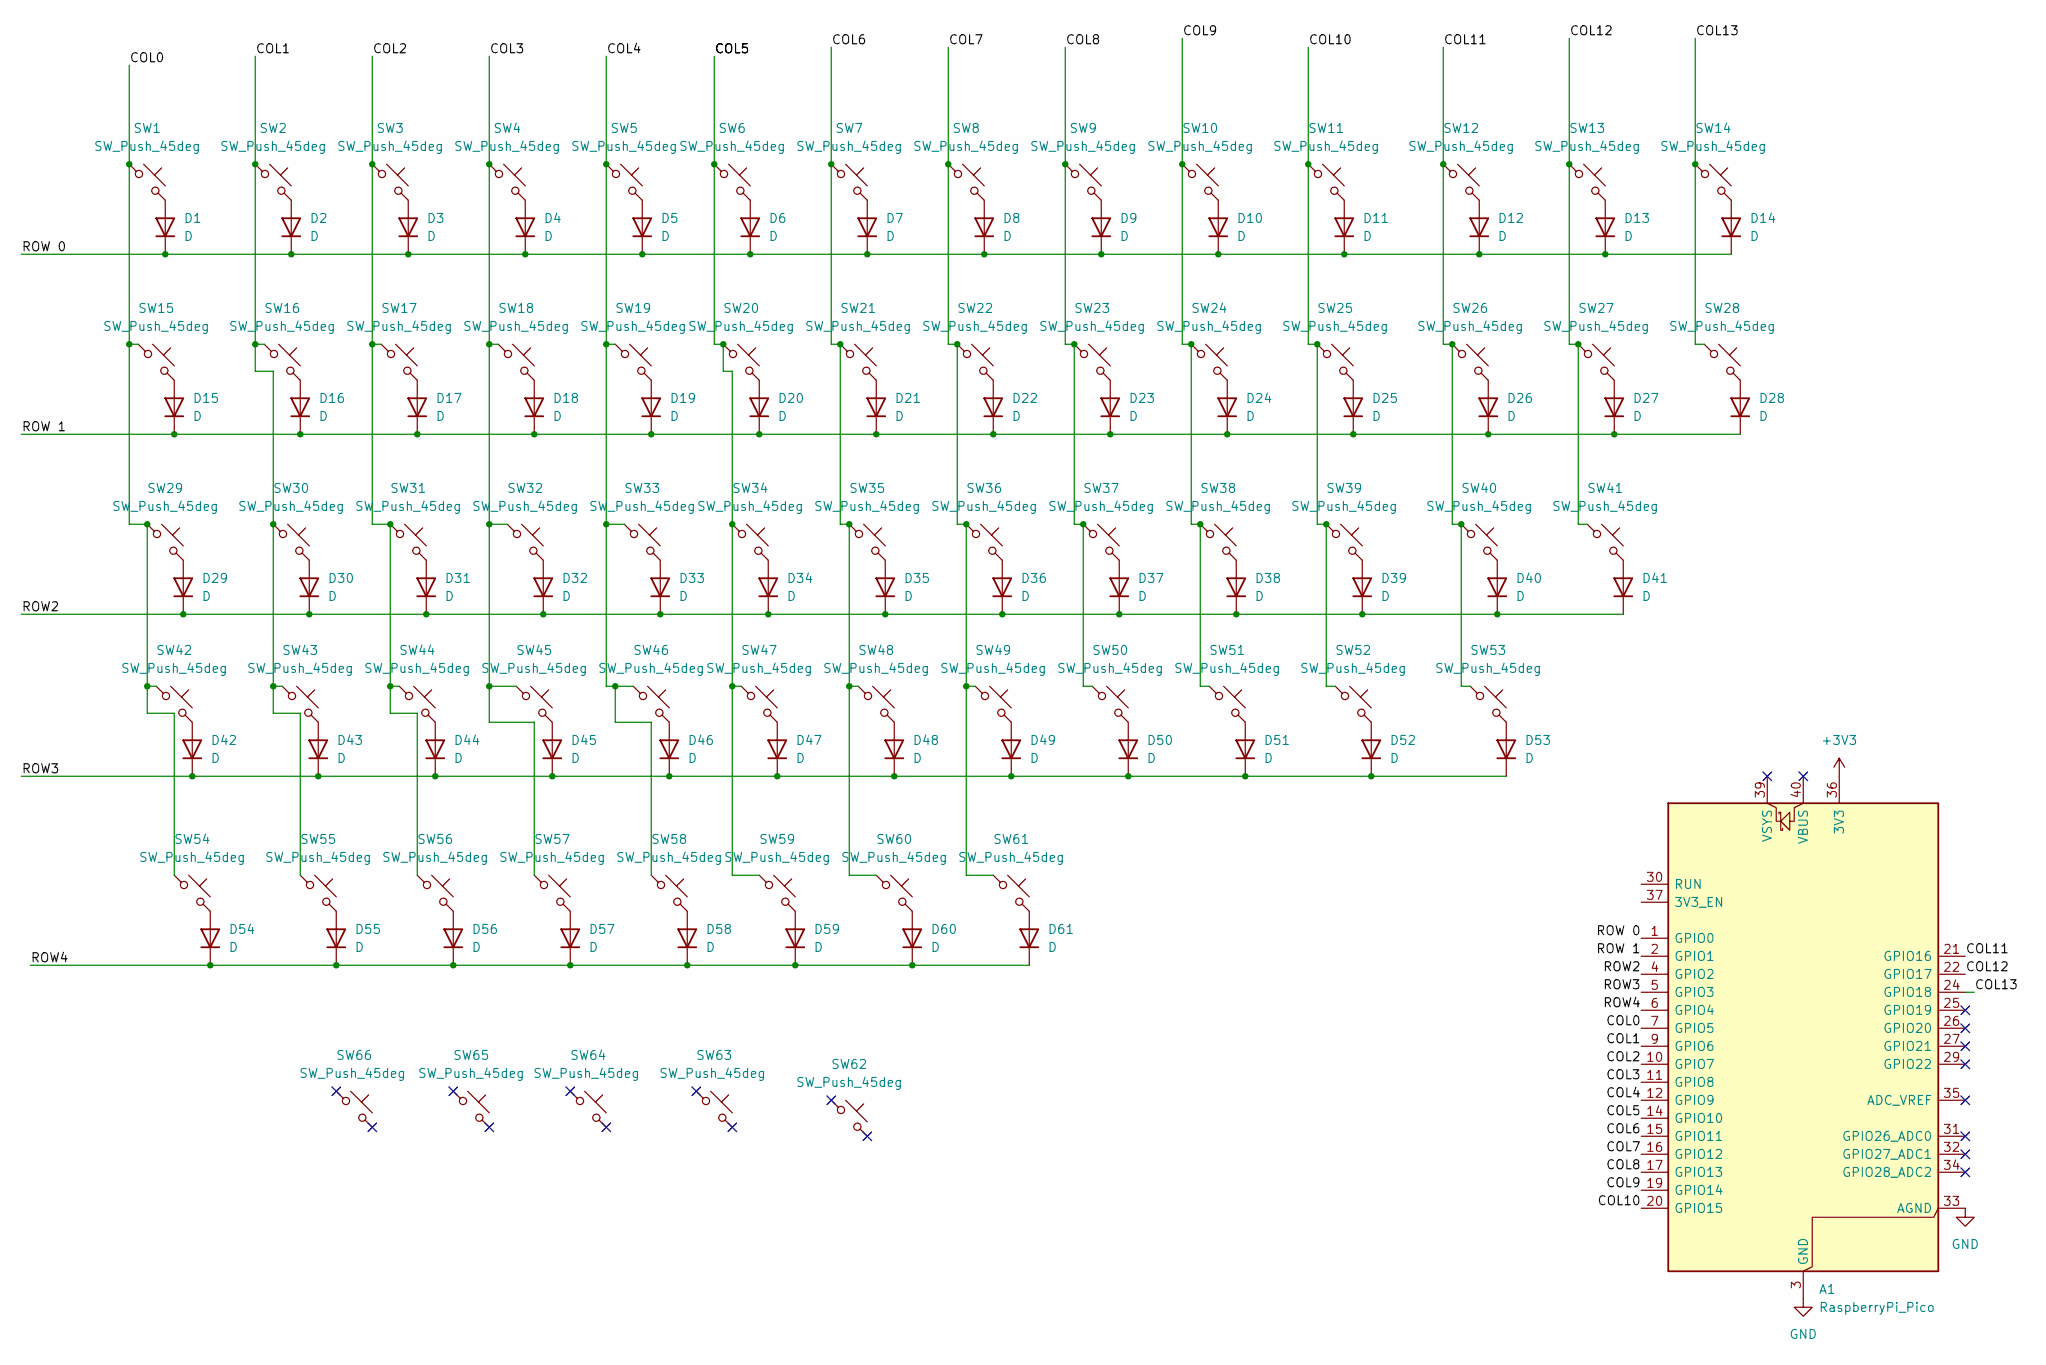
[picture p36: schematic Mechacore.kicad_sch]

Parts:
A1: RaspberryPi_Pico; RaspberryPi_Pico_Common_Unspecified
D1, D2, D3, D4, D5, D6, D7, D8, D9, D10, D11, D12, D13, D14, D15, D16, D17, D18, D19, D20, D21, D22, D23, D24, D25, D26, D27, D28, D29, D30, D31, D32, D33, D34, D35, D36, D37, D38, D39, D40, D41, D42, D43, D44, D45, D46, D47, D48, D49, D50, D51, D52, D53, D54, D55, D56, D57, D58, D59, D60, D61: D; D_SOD-123
SW1, SW2, SW3, SW4, SW5, SW6, SW7, SW8, SW9, SW10, SW11, SW12, SW13, SW16, SW17, SW18, SW19, SW20, SW21, SW22, SW23, SW24, SW25, SW26, SW27, SW30, SW31, SW32, SW33, SW34, SW35, SW36, SW37, SW38, SW39, SW40, SW43, SW44, SW45, SW46, SW47, SW48, SW49, SW50, SW51, SW52: SW_Push_45deg; SW_MX_1u
SW14: SW_Push_45deg; SW_Cherry_MX_PCB_2.00u
SW15, SW28: SW_Push_45deg; SW_MX_1.5u
SW29: SW_Push_45deg; SW_MX_1.75u
SW41, SW42: SW_Push_45deg; SW_Cherry_MX_PCB_2.25u
SW53: SW_Push_45deg; SW_Cherry_MX_PCB_2.75u
SW54, SW55, SW56, SW58, SW59, SW60, SW61: SW_Push_45deg; SW_MX_1.25u
SW57: SW_Push_45deg; SW_Cherry_MX_PCB_6.25u
SW62: SW_Push_45deg; STAB_MX_2u
SW63, SW64: SW_Push_45deg; STAB_MX_2.25u
SW65: SW_Push_45deg; STAB_MX_2.75u
SW66: SW_Push_45deg; STAB_MX_6.25u

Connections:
+3V3: A1.36 (3V3)
/COL0: A1.7 (GPIO5), SW1.1, SW15.1, SW29.1, SW42.1, SW54.1
/COL1: A1.9 (GPIO6), SW2.1, SW16.1, SW30.1, SW43.1, SW55.1
/COL2: A1.10 (GPIO7), SW3.1, SW17.1, SW31.1, SW44.1, SW56.1
/COL3: A1.11 (GPIO8), SW4.1, SW18.1, SW32.1, SW45.1, SW57.1
/COL4: A1.12 (GPIO9), SW5.1, SW19.1, SW33.1, SW46.1, SW58.1
/COL5: A1.14 (GPIO10), SW6.1, SW20.1, SW34.1, SW47.1, SW59.1
/COL6: A1.15 (GPIO11), SW7.1, SW21.1, SW35.1, SW48.1, SW60.1
/COL7: A1.16 (GPIO12), SW8.1, SW22.1, SW36.1, SW49.1, SW61.1
/COL8: A1.17 (GPIO13), SW9.1, SW23.1, SW37.1, SW50.1
/COL9: A1.19 (GPIO14), SW10.1, SW24.1, SW38.1, SW51.1
/COL10: A1.20 (GPIO15), SW11.1, SW25.1, SW39.1, SW52.1
/COL11: A1.21 (GPIO16), SW12.1, SW26.1, SW40.1, SW53.1
/COL12: A1.22 (GPIO17), SW13.1, SW27.1, SW41.1
/COL13: A1.24 (GPIO18), SW14.1, SW28.1
/ROW2: A1.4 (GPIO2), D29.1 (K), D30.1 (K), D31.1 (K), D32.1 (K), D33.1 (K), D34.1 (K), D35.1 (K), D36.1 (K), D37.1 (K), D38.1 (K), D39.1 (K), D40.1 (K), D41.1 (K)
/ROW3: A1.5 (GPIO3), D42.1 (K), D43.1 (K), D44.1 (K), D45.1 (K), D46.1 (K), D47.1 (K), D48.1 (K), D49.1 (K), D50.1 (K), D51.1 (K), D52.1 (K), D53.1 (K)
/ROW4: A1.6 (GPIO4), D54.1 (K), D55.1 (K), D56.1 (K), D57.1 (K), D58.1 (K), D59.1 (K), D60.1 (K), D61.1 (K)
/ROW 0: A1.1 (GPIO0), D1.1 (K), D2.1 (K), D3.1 (K), D4.1 (K), D5.1 (K), D6.1 (K), D7.1 (K), D8.1 (K), D9.1 (K), D10.1 (K), D11.1 (K), D12.1 (K), D13.1 (K), D14.1 (K)
/ROW 1: A1.2 (GPIO1), D15.1 (K), D16.1 (K), D17.1 (K), D18.1 (K), D19.1 (K), D20.1 (K), D21.1 (K), D22.1 (K), D23.1 (K), D24.1 (K), D25.1 (K), D26.1 (K), D27.1 (K), D28.1 (K)
GND: A1.3 (GND), A1.8 (GND), A1.13 (GND), A1.18 (GND), A1.23 (GND), A1.28 (GND), A1.33 (AGND), A1.38 (GND)
unnamed: D1.2 (A), SW1.2
unnamed: D2.2 (A), SW2.2
unnamed: D3.2 (A), SW3.2
unnamed: D4.2 (A), SW4.2
unnamed: D5.2 (A), SW5.2
unnamed: D6.2 (A), SW6.2
unnamed: D7.2 (A), SW7.2
unnamed: D8.2 (A), SW8.2
unnamed: D9.2 (A), SW9.2
unnamed: D10.2 (A), SW10.2
unnamed: D11.2 (A), SW11.2
unnamed: D12.2 (A), SW12.2
unnamed: D13.2 (A), SW13.2
unnamed: D14.2 (A), SW14.2
unnamed: D15.2 (A), SW15.2
unnamed: D16.2 (A), SW16.2
unnamed: D17.2 (A), SW17.2
unnamed: D18.2 (A), SW18.2
unnamed: D19.2 (A), SW19.2
unnamed: D20.2 (A), SW20.2
unnamed: D21.2 (A), SW21.2
unnamed: D22.2 (A), SW22.2
unnamed: D23.2 (A), SW23.2
unnamed: D24.2 (A), SW24.2
unnamed: D25.2 (A), SW25.2
unnamed: D26.2 (A), SW26.2
unnamed: D27.2 (A), SW27.2
unnamed: D28.2 (A), SW28.2
unnamed: D29.2 (A), SW29.2
unnamed: D30.2 (A), SW30.2
unnamed: D31.2 (A), SW31.2
unnamed: D32.2 (A), SW32.2
unnamed: D33.2 (A), SW33.2
unnamed: D34.2 (A), SW34.2
unnamed: D35.2 (A), SW35.2
unnamed: D36.2 (A), SW36.2
unnamed: D37.2 (A), SW37.2
unnamed: D38.2 (A), SW38.2
unnamed: D39.2 (A), SW39.2
unnamed: D40.2 (A), SW40.2
unnamed: D41.2 (A), SW41.2
unnamed: D42.2 (A), SW42.2
unnamed: D43.2 (A), SW43.2
unnamed: D44.2 (A), SW44.2
unnamed: D45.2 (A), SW45.2
unnamed: D46.2 (A), SW46.2
unnamed: D47.2 (A), SW47.2
unnamed: D48.2 (A), SW48.2
unnamed: D49.2 (A), SW49.2
unnamed: D50.2 (A), SW50.2
unnamed: D51.2 (A), SW51.2
unnamed: D52.2 (A), SW52.2
unnamed: D53.2 (A), SW53.2
unnamed: D54.2 (A), SW54.2
unnamed: D55.2 (A), SW55.2
unnamed: D56.2 (A), SW56.2
unnamed: D57.2 (A), SW57.2
unnamed: D58.2 (A), SW58.2
unnamed: D59.2 (A), SW59.2
unnamed: D60.2 (A), SW60.2
unnamed: D61.2 (A), SW61.2

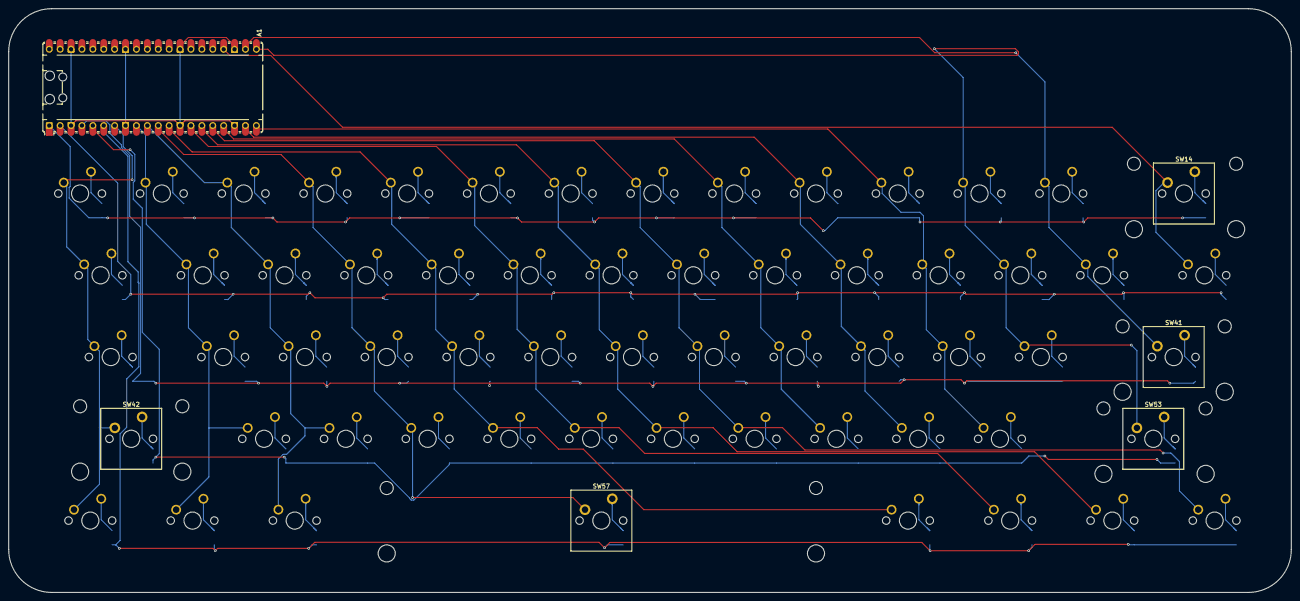
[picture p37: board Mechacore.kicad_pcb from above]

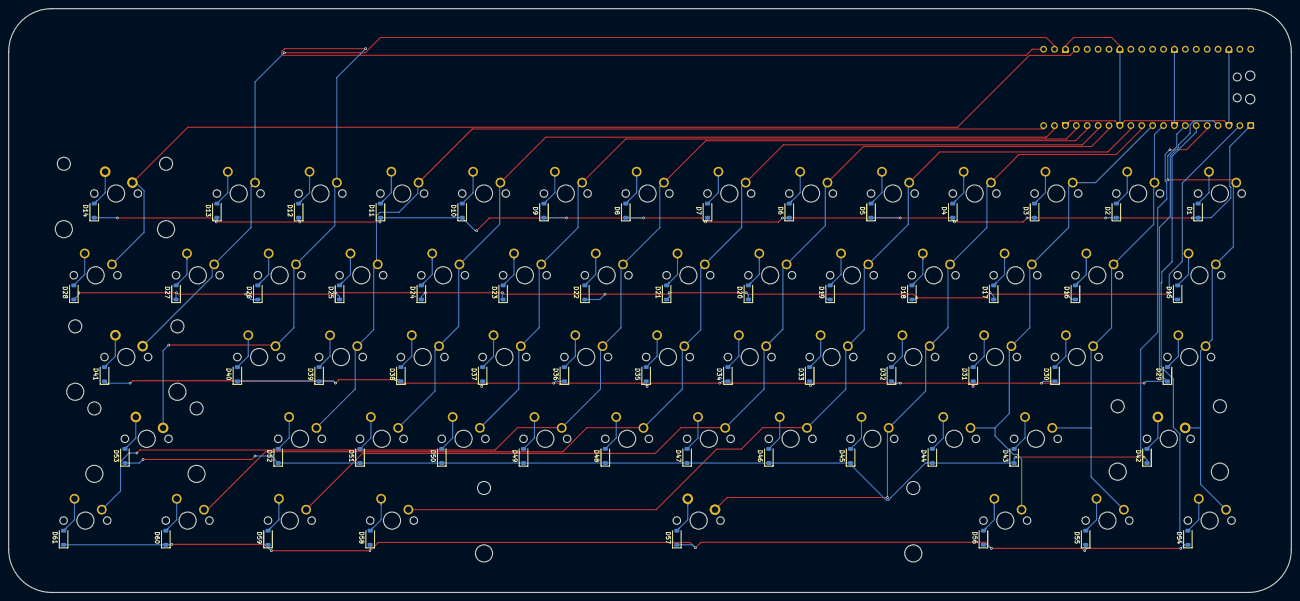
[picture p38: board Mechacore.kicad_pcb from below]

Board: 2 copper layers, 298.8 x 136.0 mm, 128 parts (61 on the bottom side), 81 nets.

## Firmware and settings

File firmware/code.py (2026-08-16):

import board
import keypad
import time
import usb_hid

ROWS = (board.GP0, board.GP1, board.GP2, board.GP3, board.GP4)
COLS = (
    board.GP5,
    board.GP6,
    board.GP7,
    board.GP8,
    board.GP9,
    board.GP10,
    board.GP11,
    board.GP12,
    board.GP13,
    board.GP14,
    board.GP15,
    board.GP16,
    board.GP17,
    board.GP18,
)

CONSUMER = 0x10000
PREVIOUS_TRACK = CONSUMER + 0xB6
NEXT_TRACK = CONSUMER + 0xB5
PLAY_PAUSE = CONSUMER + 0xCD
MUTE = CONSUMER + 0xE2
VOLUME_UP = CONSUMER + 0xE9
VOLUME_DOWN = CONSUMER + 0xEA

BASE = (
    (0x35, 0x1E, 0x1F, 0x20, 0x21, 0x22, 0x23, 0x24, 0x25, 0x26, 0x27, 0x2D, 0x2E, 0x2A),
    (0x2B, 0x14, 0x1A, 0x08, 0x15, 0x17, 0x1C, 0x18, 0x0C, 0x12, 0x13, 0x2F, 0x30, 0x31),
    (0x39, 0x04, 0x16, 0x07, 0x09, 0x0A, 0x0B, 0x0D, 0x0E, 0x0F, 0x33, 0x34, 0x28, 0),
    (0xE1, 0x1D, 0x1B, 0x06, 0x19, 0x05, 0x11, 0x10, 0x36, 0x37, 0x38, 0xE5, 0, 0),
    (0xE0, 0xE3, 0xE2, 0x2C, 0xE6, 0xE7, 0, 0xE4, 0, 0, 0, 0, 0, 0),
)

FN_LAYER = (
    (0x29, 0x3A, 0x3B, 0x3C, 0x3D, 0x3E, 0x3F, 0x40, 0x41, 0x42, 0x43, 0x44, 0x45, 0x4C),
    (None, PREVIOUS_TRACK, PLAY_PAUSE, NEXT_TRACK, None, None, None, 0x4A, 0x52, 0x4D, 0x4B, None, None, None),
    (None, None, None, None, None, None, None, 0x50, 0x51, 0x4F, 0x4E, None, None, None),
    (None, None, None, None, None, None, None, MUTE, VOLUME_DOWN, VOLUME_UP, PLAY_PAUSE, None, None, None),
    (None, None, None, None, None, None, None, None, None, None, None, None, None, None),
)

FN_POSITION = 62
MENU_KEY = 0x65
FN_DELAY = 0.18


def key_for(position, fn_active):
    row, column = divmod(position, len(COLS))
    if fn_active:
        value = FN_LAYER[row][column]
        if value is not None:
            return value
    return BASE[row][column]


class Hid:
    def __init__(self):
        self.keyboard = None
        self.consumer = None
        self.last_keyboard = None
        self.last_consumer = None

        for device in usb_hid.devices:
            if device.usage_page == 0x01 and device.usage == 0x06:
                self.keyboard = device
            elif device.usage_page == 0x0C:
                self.consumer = device

        if self.keyboard is None or self.consumer is None:
            raise RuntimeError("USB HID devices are missing")

    def send(self, device, report, previous):
        if report == previous:
            return previous, True
        try:
            device.send_report(report)
        except OSError:
            return previous, False
        return report, True

    def update(self, positions, fn_active, extra=()):
        usages = []
        for position in sorted(positions):
            if position != FN_POSITION:
                usage = key_for(position, fn_active)
                if usage:
                    usages.append(usage)
        usages.extend(extra)

        modifiers = 0
        regular = []
        consumer = 0

        for usage in usages:
            if usage >= CONSUMER:
                if consumer == 0:
                    consumer = usage - CONSUMER
            elif 0xE0 <= usage <= 0xE7:
                modifiers |= 1 << (usage - 0xE0)
            elif usage not in regular:
                regular.append(usage)

        keyboard_report = bytearray(8)
        keyboard_report[0] = modifiers
        if len(regular) > 6:
            for index in range(2, 8):
                keyboard_report[index] = 0x01
        else:
            for index, usage in enumerate(regular):
                keyboard_report[index + 2] = usage

        consumer_report = bytes((consumer & 0xFF, consumer >> 8))
        self.last_keyboard, keyboard_ok = self.send(
            self.keyboard,
            bytes(keyboard_report),
            self.last_keyboard,
        )
        self.last_consumer, consumer_ok = self.send(
            self.consumer,
            consumer_report,
            self.last_consumer,
        )
        return keyboard_ok and consumer_ok

    def tap(self, positions, fn_active, usage):
        deadline = time.monotonic() + 0.2
        while time.monotonic() < deadline:
            if self.update(positions, fn_active, (usage,)):
                break
            time.sleep(0.005)
        time.sleep(0.012)
        self.update(positions, fn_active)


def run():
    matrix = keypad.KeyMatrix(
        row_pins=ROWS,
        column_pins=COLS,
        columns_to_anodes=True,
        interval=0.002,
        max_events=64,
        debounce_threshold=3,
    )
    hid = Hid()
    pressed = set()
    fn_started = None
    fn_active = False
    fn_used = False

    while True:
        now = time.monotonic()
        if fn_started is not None and not fn_active and now - fn_started >= FN_DELAY:
            fn_active = True
            fn_used = True

        event = matrix.events.get()
        while event is not None:
            position = event.key_number

            if position == FN_POSITION:
                if event.pressed:
                    pressed.add(position)
                    fn_started = time.monotonic()
                    fn_active = False
                    fn_used = False
                else:
                    pressed.discard(position)
                    tapped = fn_started is not None and not fn_used
                    fn_started = None
                    fn_active = False
                    hid.update(pressed, fn_active)
                    if tapped:
                        hid.tap(pressed, fn_active, MENU_KEY)
            elif event.pressed:
                pressed.add(position)
                if fn_started is not None:
                    fn_active = True
                    fn_used = True
            else:
                pressed.discard(position)

            event = matrix.events.get()

        hid.update(pressed, fn_active)
        time.sleep(0.001)


if __name__ == "__main__":
    run()

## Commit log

2026-08-16 Initial MechaCore release
    [Bottom case.stl, Mechacore.f3d, Mechacore.kicad_pcb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]
2026-08-16 Add Pico 2 keyboard firmware
2026-08-22 Add overengineered two-piece case revisions
    [Bottom-case-fused-revD.stl, Bottom-case-mounting-revB.stl, Bottom-case-overengineered-revC.stl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]
